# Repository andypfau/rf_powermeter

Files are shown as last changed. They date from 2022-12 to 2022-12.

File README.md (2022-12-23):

RF Powermeter
=============

A 10 MHz to 8 GHz RF power meter with USB connectivity.

## Design



## Photos

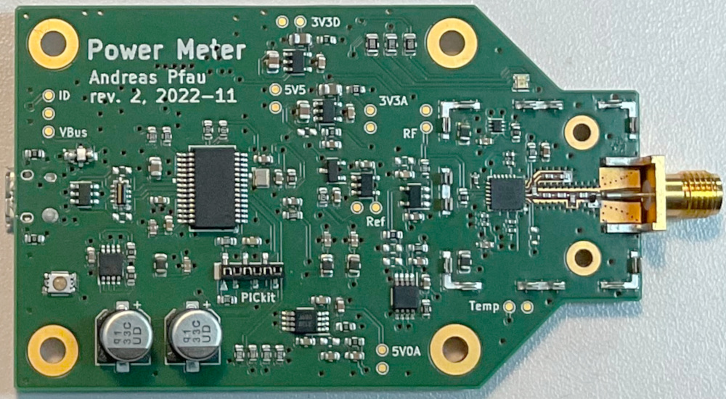
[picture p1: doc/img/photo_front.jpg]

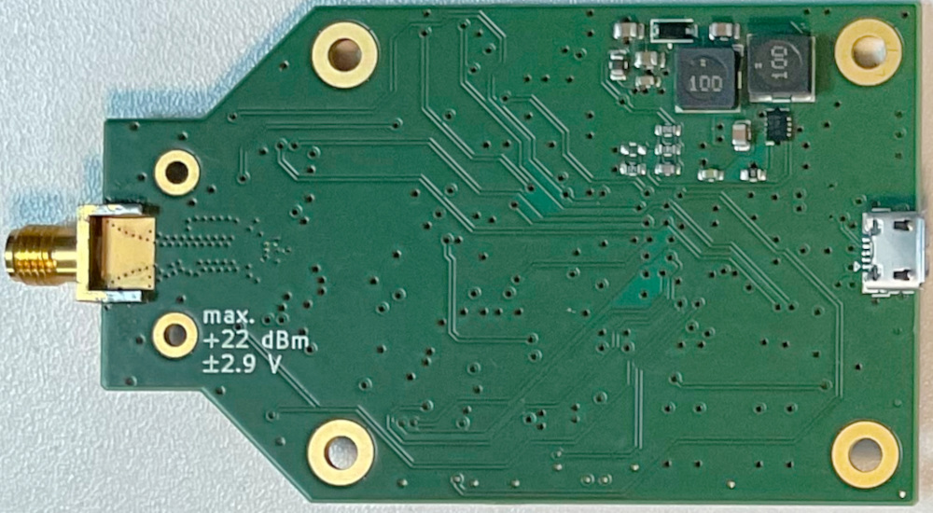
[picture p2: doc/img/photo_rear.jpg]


## Project Status

The hardware is working. The firmware is considered beta, but all functionality is implemented, and should work.

### Thoughts on Design

- The SMA connector is quite cheap, and will probably not last long (no stainless steel). Also, with the current design, the SMA tighening torque might break the solder connectio to the PCB (happened during testing).
- The HMC602 is EOL (see production notes below).

## Further Reading

- [RF Design](./doc/rfdesign.md)
- [Design Tools](./doc/designtools.md)
- [Production](./doc/production.md)
- [Serial Interface](./doc/serial.md)
- [Measurements](./doc/measurements.md)
- [Hardware Revisions](./doc/hwrev.md)

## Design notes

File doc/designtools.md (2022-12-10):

Design Tools
============

- PCB: [KiCad 6](https://www.kicad.org/)
- MCU: [MPLABX 6 IDE](https://www.microchip.com/en-us/tools-resources/develop/mplab-x-ide), [PICkit 4](https://www.microchip.com/en-us/education/developer-help/learn-tools-software/programmers-debuggers/pickit4)

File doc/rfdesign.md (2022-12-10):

RF Design
=========

## PCB Stackup

The PCB was produced with the 4-layer stackup from [Aisler](https://aisler.net/) (as of 2022):

| Layer | Base Th. | Final Th. | Material | εr | Df |
|---|---|---|---|---|---|
| Mask  | | | Elppemer AS 2467 SM-DG | 3.70 | |
| Top | 18 µm | 40 µm | Copper | | |
| | 69 µm | 68.13 µm  | Prepreg 1080 / R-1551 (W) | 4.30 | 0.013 |
| | 69 µm | 68.13 µm  | Prepreg 1080 / R-1551 (W) | 4.30 | 0.013 |
| 2 | 35 µm | 35 µm | Copper | | |
| | 1130 µm  | 1130 µm | FR4 Core / R-1566 (W) | 4.60 | 0.010 |
| 3 | 35 µm | 35 µm | Copper | | |
| | 69 µm | 68.13 µm  | Prepreg 1080 / R-1551 (W) | 4.30 | 0.013 |
| | 69 µm | 68.13 µm  | Prepreg 1080 / R-1551 (W) | 4.30 | 0.013 |
| Bot.  | 18 µm | 40 µm | Copper | | |
| Mask  | | | Elppemer AS 2467 SM-DG | 3.70 | |

The dielectric parameters are in the range from 2..6 GHz; for more details, [see here](https://industrial.panasonic.com/ww/products/pt/halogen-free/models/R-1566%25252FR-1551).

## RF Structures

The RF structures were simulated and optimized in [CST](https://www.3ds.com/products-services/simulia/products/cst-studio-suite/).

### Coplanar Waveguide

S-Parameters of a 20 mm trace:

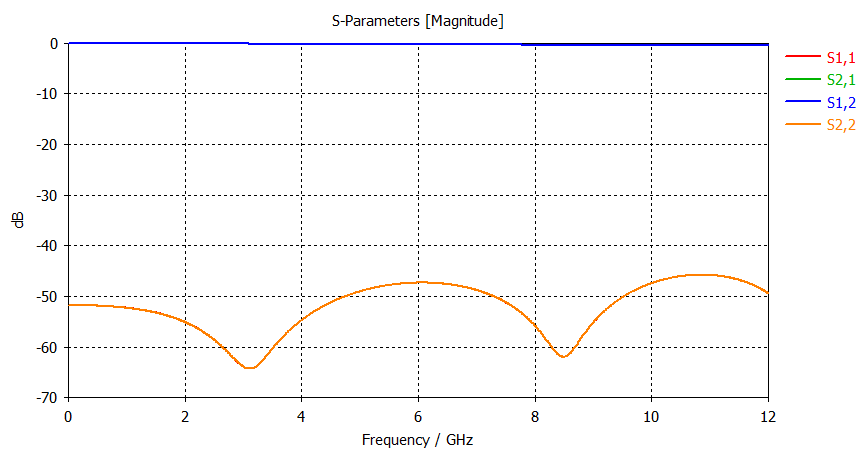
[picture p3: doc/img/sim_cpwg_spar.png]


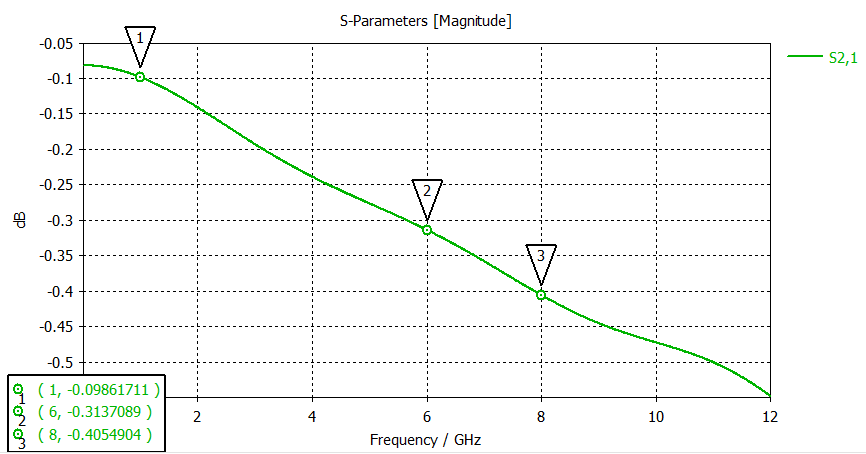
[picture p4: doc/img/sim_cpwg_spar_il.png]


| Frequency | Loss |
|---|---|
| 1 GHz | 0.049 dB/cm |
| 6 GHz | 0.16 dB/cm  |
| 8 GHz | 0.20 dB/cm  |

Geometry:

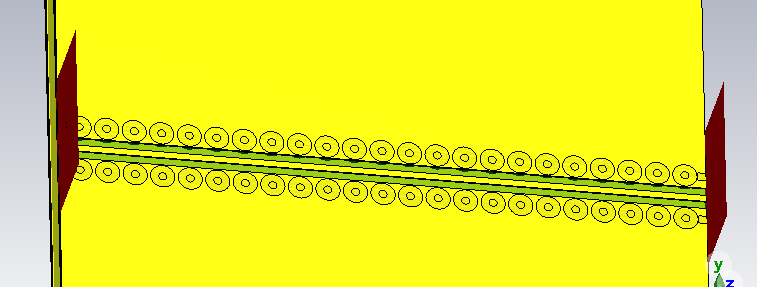
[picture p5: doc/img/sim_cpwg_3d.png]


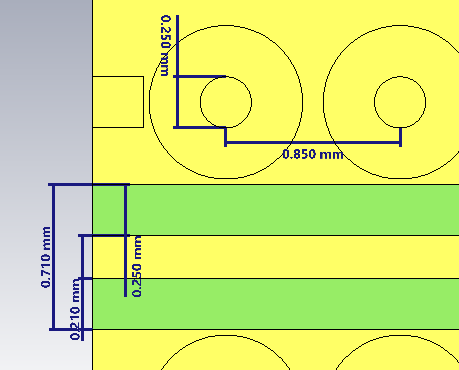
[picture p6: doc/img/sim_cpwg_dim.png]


#### Sensitivity

Swept Parameters:

- Tline width: ±0.3 mm
- Prepreg thickness: ±20 µm
- Prepreg Dk: ±0.1 → almost no impact

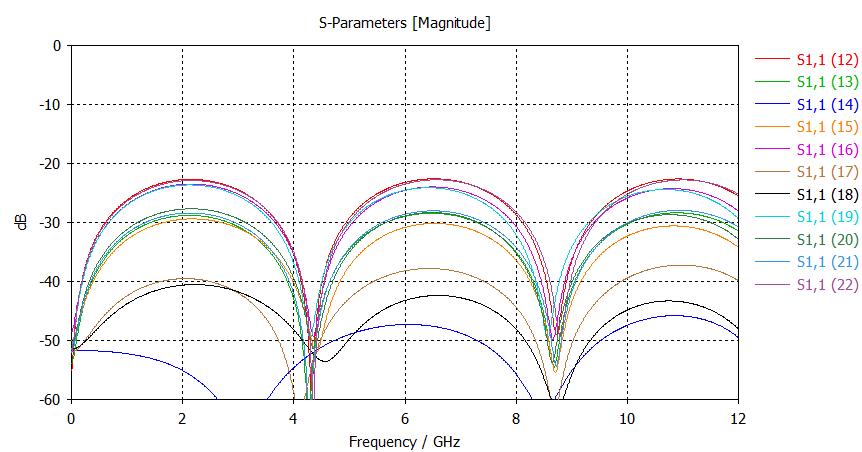
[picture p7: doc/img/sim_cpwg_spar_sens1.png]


Swept Parameters:

- Via diameter: 0.25 mm, 0.50 mm
- Via annular ring: 0.25 mm, 0.50mm
- Gap between annular rings is fixed at 0.025 mm.

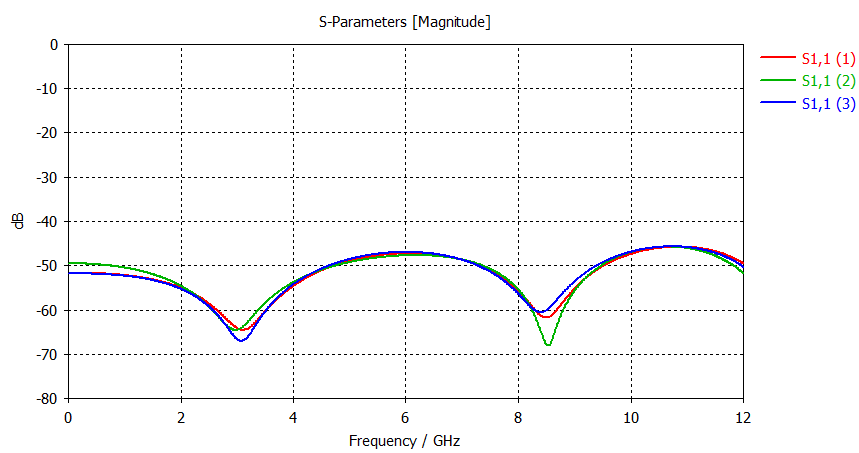
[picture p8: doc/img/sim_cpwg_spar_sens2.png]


### SMA Transition

S-Parameters:

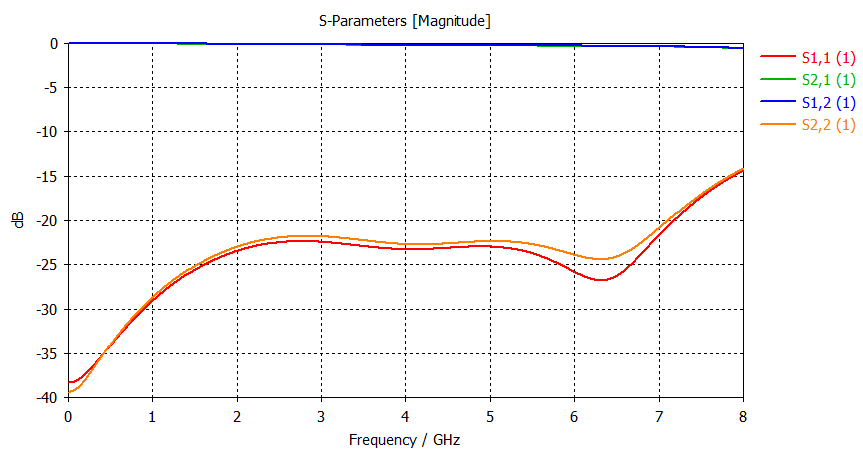
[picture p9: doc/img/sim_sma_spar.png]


Geometry:

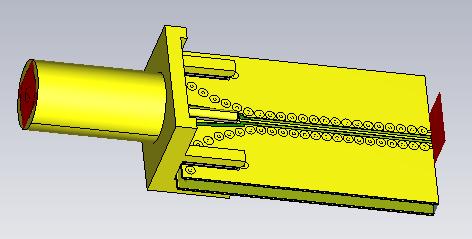
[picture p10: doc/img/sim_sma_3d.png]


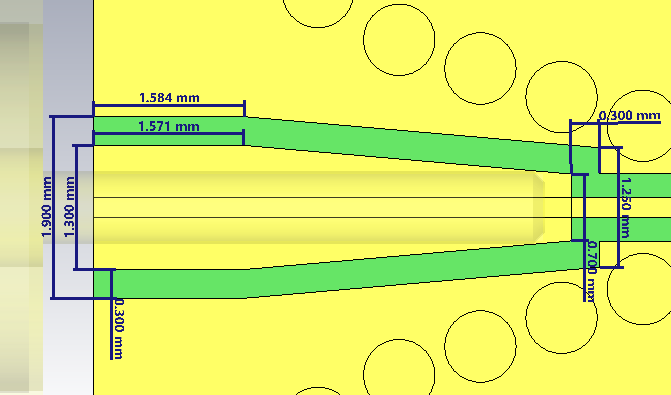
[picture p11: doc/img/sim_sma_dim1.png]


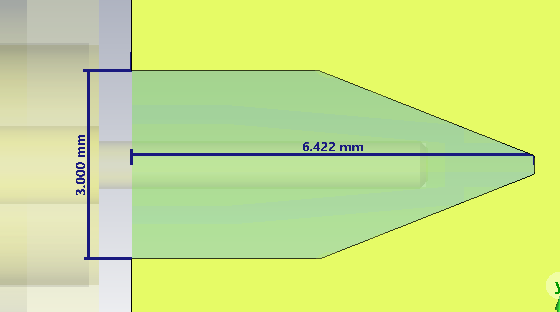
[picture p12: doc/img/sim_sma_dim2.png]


### 0402 Resistors

S-Parameters:

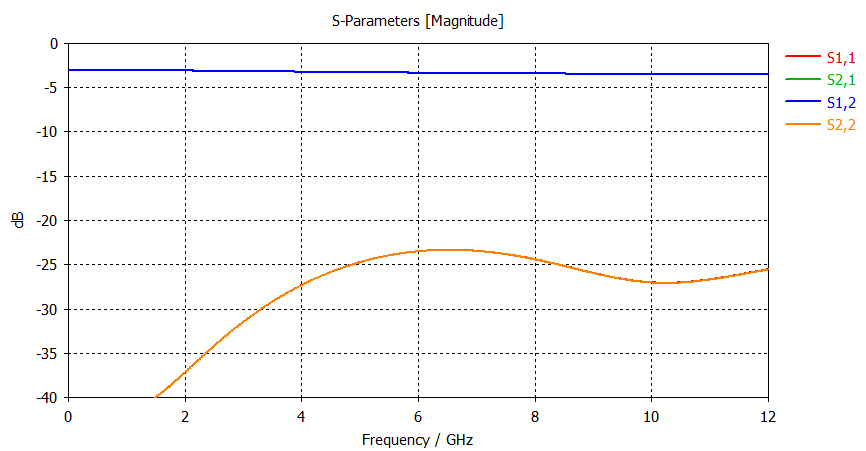
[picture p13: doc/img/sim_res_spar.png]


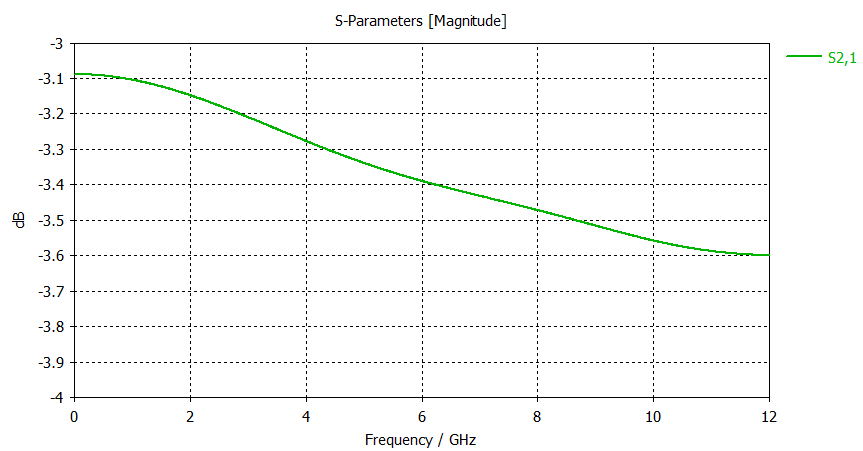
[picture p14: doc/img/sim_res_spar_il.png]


Impact of GND-Cutout:

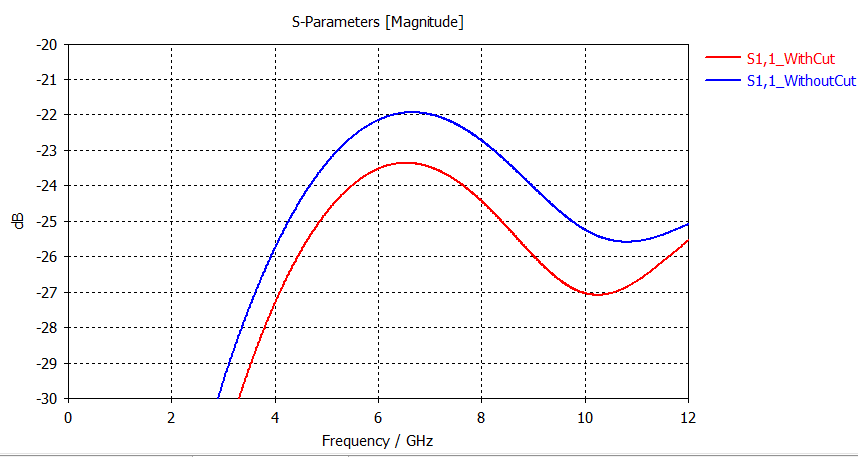
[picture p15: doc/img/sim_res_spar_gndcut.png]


Geometry:

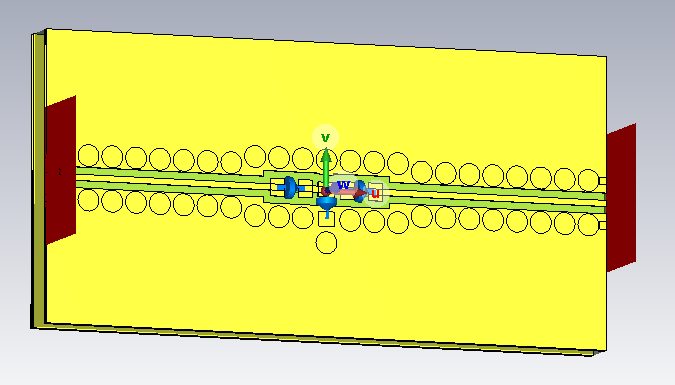
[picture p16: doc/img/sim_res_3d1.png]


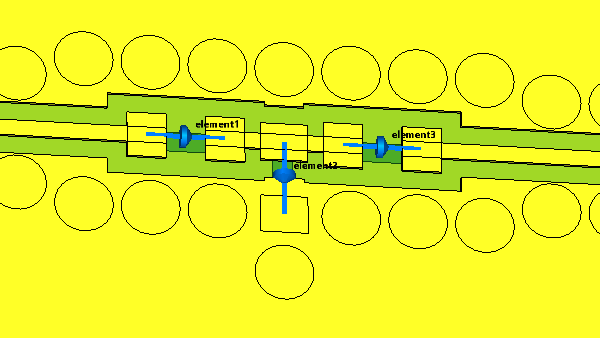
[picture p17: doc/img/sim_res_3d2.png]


Top Cu:

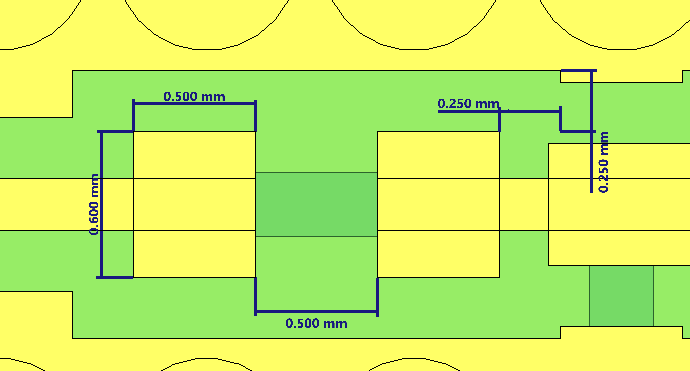
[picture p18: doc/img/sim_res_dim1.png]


Inner (GND) Cu:

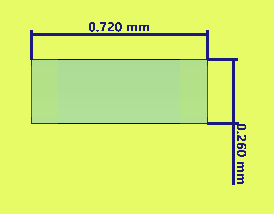
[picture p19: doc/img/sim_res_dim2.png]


## QFN Transition

S-Parameters:

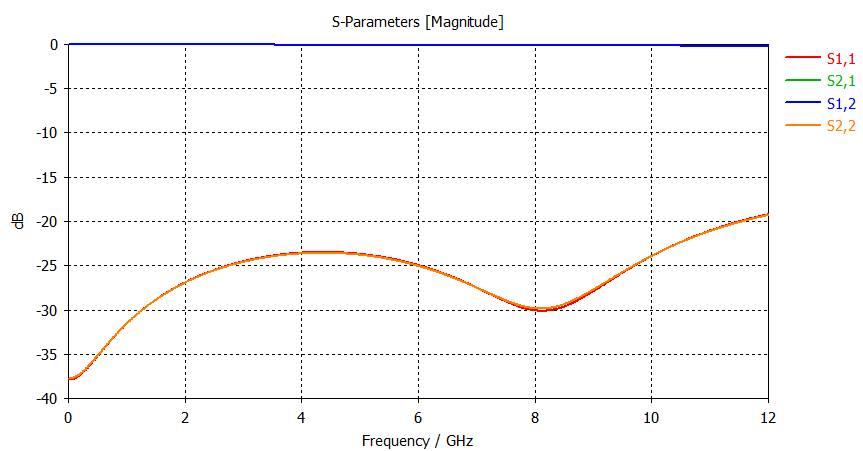
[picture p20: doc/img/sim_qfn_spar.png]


Geometry:

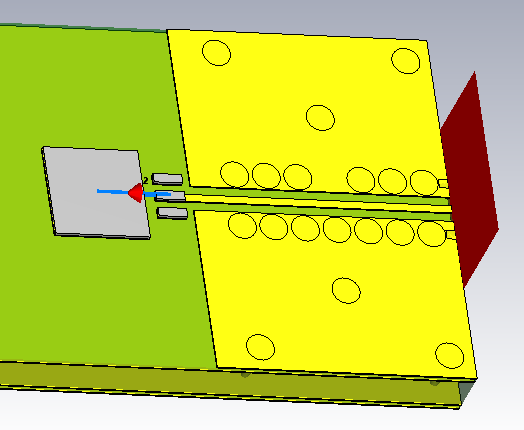
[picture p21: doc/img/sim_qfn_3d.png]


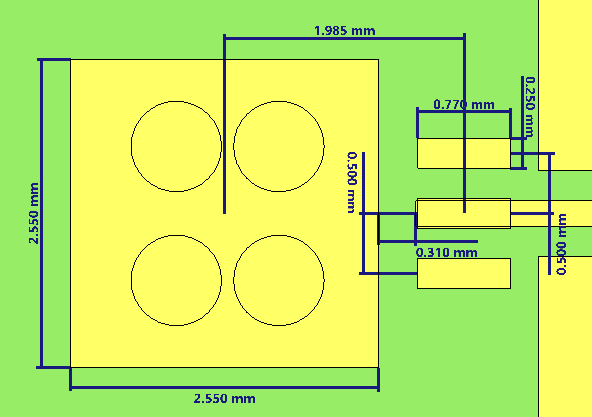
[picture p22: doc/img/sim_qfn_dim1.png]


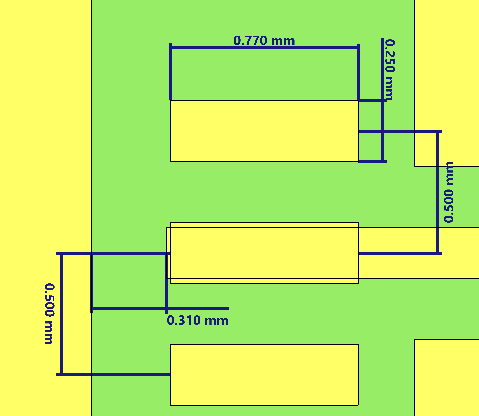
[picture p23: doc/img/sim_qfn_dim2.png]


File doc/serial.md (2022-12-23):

Serial Interface
================

# Getting Started

1. Connect the Powermeter via USB to your PC
	- both under Windows and under Linux, a virtual serial port should be detected without drivers needed
2. Connect to the virtual serial port e.g. with *PuTTY*, or e.g. with the `screen` command

# UI Mode

Press the `Esc` key to enter UI mode.

	-35.103 dB
	
	          v
	| ' | ' | ' | ' | ' | ' | ' |
	
	Cnt  Avg 16  3000 MHz

Valid commands:

- `a`: enter number of averages (must be a power of 2, in the range 1..512)
- `c`: continuous trigger mode
- `d`: display diagnostic data
- `t`: trigger a single measurement
- `f`: enter frequency in MHz (for compensation data; must be in the range 10..8000)
- `h`: display help
- `l`: turn compensation on/off
- `Esc`: re-draw the screen

# Remote Mode

Send a `\0` character (i.e. ASCII code zero) to enter remote mode. All commands and responses are terminated by `\n` (i.e. ASCII code 10) Valid commands:

- `a<int>\n`: set number of averages
	- Must be a power of two
	- E.g. `a32\n` to set 32 averages
- `d\n`: diagnostics
	- Returns three semicolon-separated list of three values: the measured voltage of 5V0USB (USB bus voltage) in volts, the measured voltage of 5V0A (analog supply) in volts, and the tmeperature sensor reading on °C
	- E.g. `d\n` → `4.999;5.010;32.105\n`
- `e\n`: get last error
	- Returns an error code that is zero in the case of no error.
	- E.g. `e\n` → `0\n`
- `f<int>\n`: set frequency, in MHz
	- Must be in the range 10..8000
	- E.g. `f1100\n` to set to 1.1 GHz
- `l<int>\n`: enable/disable compensation
	- Must be 1 (enable) or 0 (disable)
	- E.g. `l1\n` to enable compensation
- `m<r|w><hex><hex>\n`: access EEPROM
	- Read from memory: send `r`, followed by exactly four hexadecimal digits (address); the response will be exactly four hexadecimal digits (data)
	- Write to memory: send `w`, followed by exactly four hexadecimal digits (address), followed by exactly four hexadecimal digits (data)
	- E.g. `mw00010002\n` to write 0x0002 to address 0x0001
	- E.g. `mr0001\n` to read from address 0x0001 → e.g. `0002\n`
- `t\n`: trigger a measurement
	- Ehe response will be sent as a signed floating-point string, followed by `\n`
	- E.g. `t\n` → `-30.205\n`
- `\0`: enter remote mode

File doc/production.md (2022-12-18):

Production
==========

## Tools and Material

- PCB and stencil: [Aisler 4-layer](https://aisler.net/)
- Stencil registration tool: [Eurocrictuis ec manual tool](https://www.eurocircuits.de/ec-registration-system-details-platine-schablone/)
- Tools for pick&place: VAC-12000 vacuum pickup, [SWIFT S41-20 Binocular Stereo Microscope](https://us.swiftmicroscopes.com/collections/stereo-microscope/products/swift-s41-20-binocular-stereo-microscope-with-10x-20x-and-1w-led-illumination)
- Solder paste: [Chipquik NC191SNL50T5](https://www.chipquik.com/store/product_info.php?products_id=473023) (Sn96.5/Ag3.0/Cu0.5, 217..220 °C melting point, no-clean flux, T5 / 15-25 microns)
- Vapor phase liquid: [Galden HS240](https://www.solvay.com/en/brands/galden-pfpe) (240 °C boiling point)

## Notes on Components

The key component, the [HMC602LP4E](https://www.analog.com/en/products/hmc602.html) RF power sensor, was [discontinued](https://www.analog.com/media/en/PCN/ADI_PDN_22_0023_Rev_B_Form.pdf) shortly after I started the project.

There is no pin-compatible replacement, but ADI recommends the [AD8318](https://www.analog.com/en/products/ad8318.html) as a replacement. At a first glance, it looks like it could be used with only small PCB modifications. However, it has a different pitch (0.65 mm vs. 0.5 mm), so the pad geometry may have to be adjusted.

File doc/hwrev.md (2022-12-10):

Hardware Revisions
==================

##  Rev. 1
- Problems:
	- USB D+ and D- lines are crossed → use flipped USB connector instead.
	- RF component footprints have solder resist on the pads → revise solder mask.
	- HMC602 footprint does not fit (pads are wider than package).

## Rev. 2
- Problems:
	- Pin numbering of button symbol is wrong (causes PGC to be shorted).
	- RF Temp requires a voltage divider towards MCU
	- Moved USB connector to PCB rear side (to swap D+ and D-).
- Changes:
	- Fixed solder resist on RF component footprints
	- Revised HMC602 footprint (pads were wider than package).
	- Fixed TMP112 footprint (pads were too wide).
	- Added more drill-holes close to RF connector.

## Rev. 3
Not produced yet.

- Changes:
	- Fixed button symbol and layout.
	- Added voltage divider between RF Temp output and MCU ADC input.
- Ideas:
	- Add "GND-island" around DCDC.
	- Add a GND clamp for easier hardware-debugging.

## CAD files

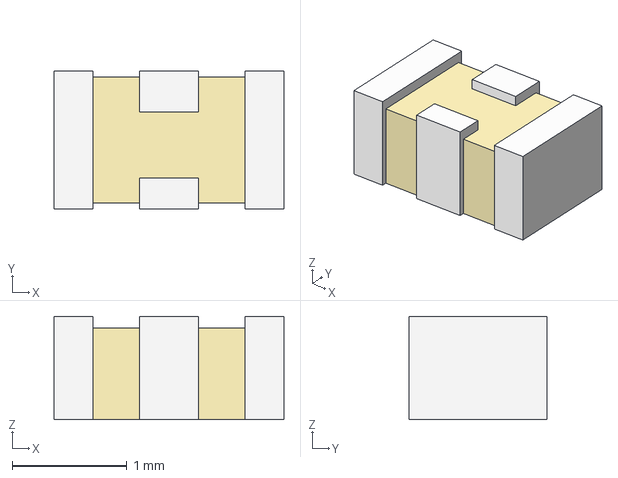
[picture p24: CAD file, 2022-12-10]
hardware/KiCad/3d/Capacitor_Feedthru_0805.step
2.00 x 1.20 x 0.9 mm

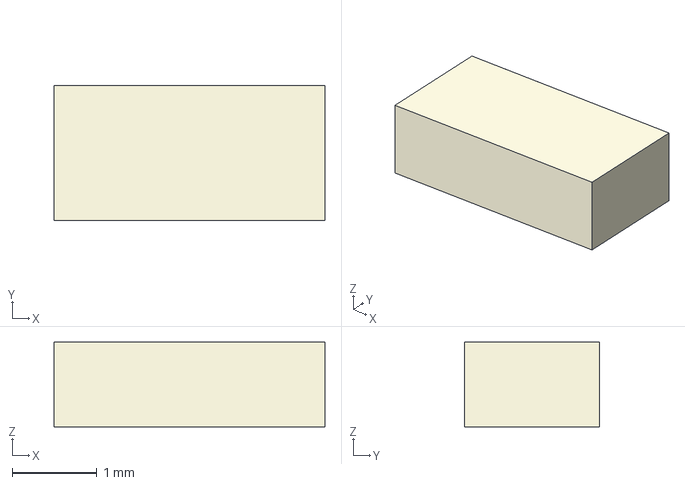
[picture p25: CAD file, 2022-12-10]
hardware/KiCad/3d/EZA-DLU.stp
3.20 x 1.60 x 1.00 mm

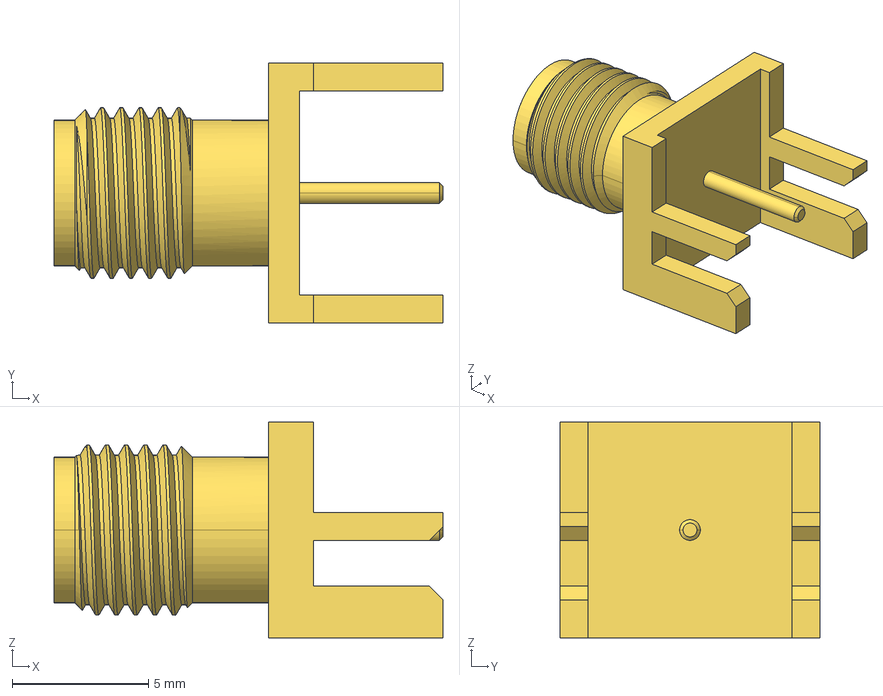
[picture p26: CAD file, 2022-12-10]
hardware/KiCad/3d/Molex_SMA_732511150.stp
14.3 x 9.53 x 7.92 mm

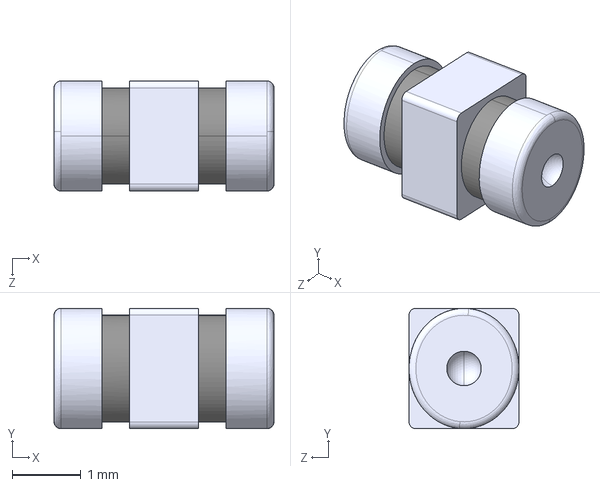
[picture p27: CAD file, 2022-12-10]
hardware/KiCad/3d/NFE31PT471F1E9L.step
3.20 x 1.75 x 1.60 mm

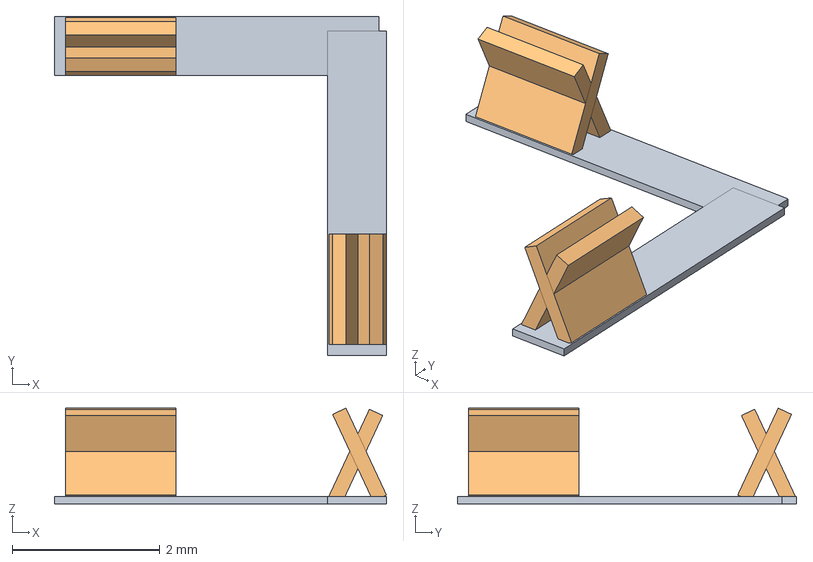
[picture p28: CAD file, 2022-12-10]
hardware/KiCad/3d/S0981-46R.stp
4.50 x 4.60 x 1.30 mm

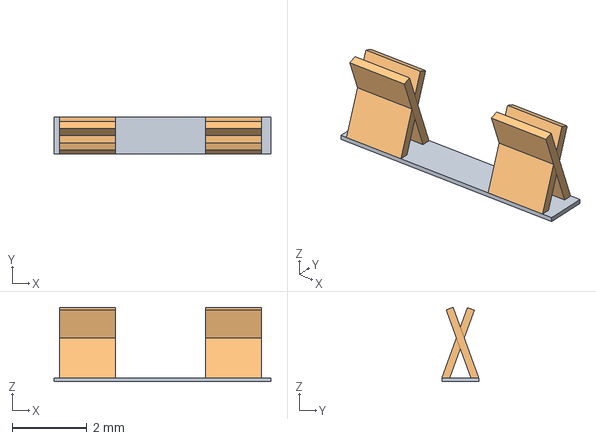
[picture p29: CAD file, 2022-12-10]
hardware/KiCad/3d/S0971-46R.stp
5.80 x 1.00 x 1.99 mm

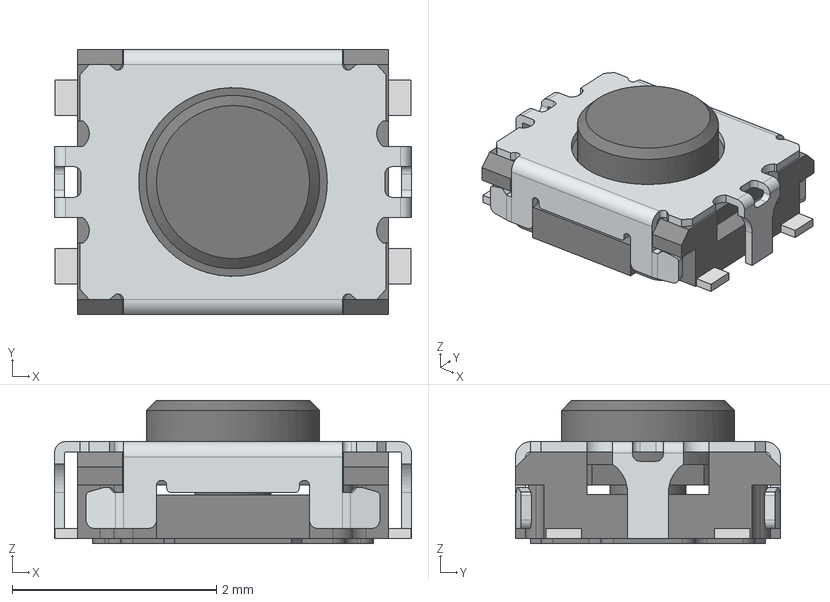
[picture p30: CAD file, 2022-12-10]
hardware/KiCad/3d/STP_4351x10148xx (rev1).stp
3.50 x 2.60 x 1.40 mm
Base
Stem
Frame
Pin x 4

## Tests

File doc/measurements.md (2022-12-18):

Measurements
============

## Summary

- Return Loss: -12 dB up to 6 GHz, which is good enough for a hobby project.
- Measurement error: no dips/resonances/etc, can easily be compensated with LUT.
- Linearity: around 1 dB error over a 20 dB range, which is more than expected, but acceptable for a hobby project.
- Generated noise: no significant noise detected.

The DUT reported a temperature of 38 °C during the measurement.

## RF Measurements

### Return Loss

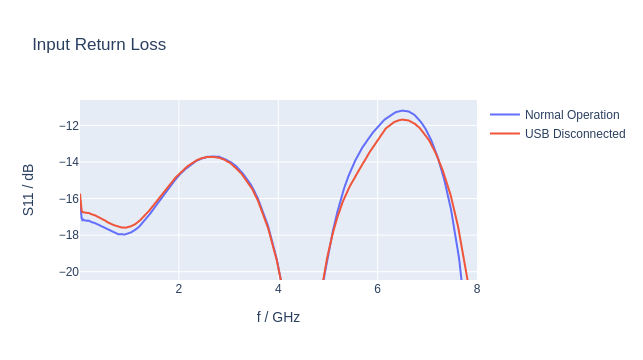
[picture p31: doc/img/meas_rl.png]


Setup: powermeter → network analyzer.

### Measurement Error

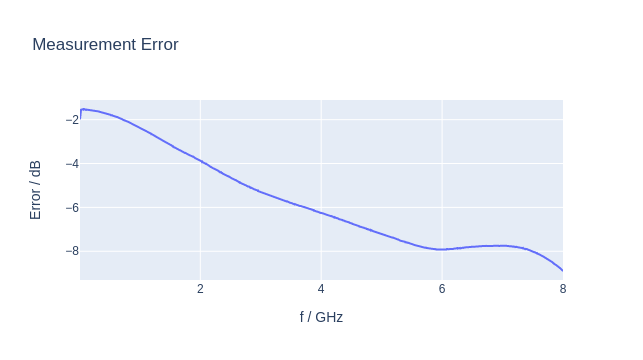
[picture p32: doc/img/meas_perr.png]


Setup: signal source → power divider → powermeter (bench instrument) | powermeter (DUT).

There is a small systematic error, because there were different adapters on each leg of the divider.

#### Linearity

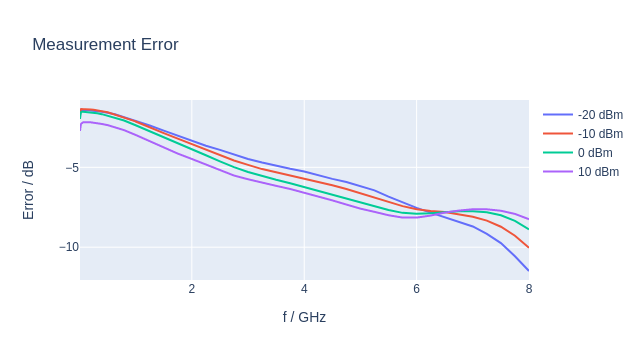
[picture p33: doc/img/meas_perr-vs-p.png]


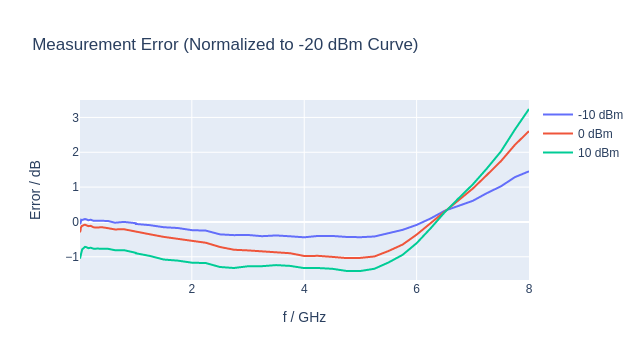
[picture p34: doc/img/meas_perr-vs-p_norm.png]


### Generated Noise

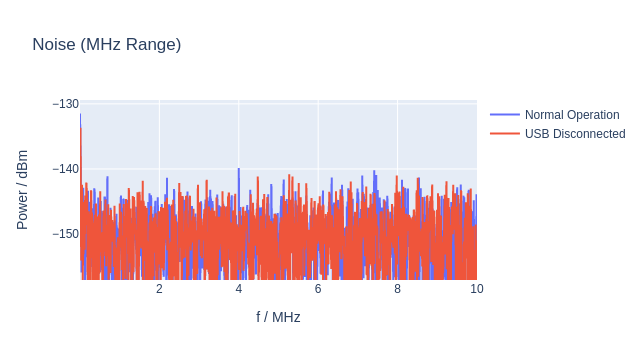
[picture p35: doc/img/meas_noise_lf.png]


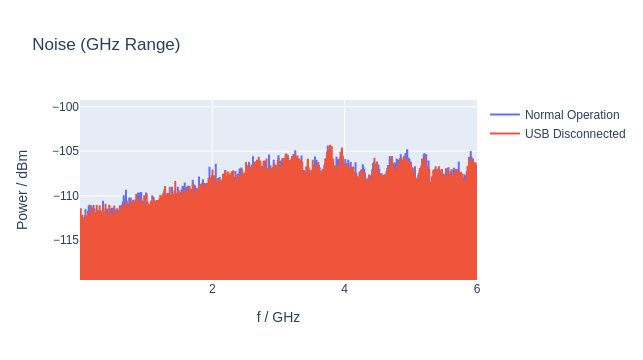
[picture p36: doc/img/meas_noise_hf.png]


Setup: powermeter → spectrum analyzer.

For the different frequency ranges, the measured noisefloor levels differ; this is because the RBW was changed, in order to speed up the measurement time. However, the measurements show that there is no change in noisefloor when turning the DUT on or off.

## DC Rail measurements

### Levels

- 5V0USB: 4.79 V
- 5V5: 5.64 V
- 5V0A: 4.99 V
- 3V3A: 3.29 V
- 3V3D: 3.29 V
- Ref: 2.998 V
- RF: 2.05 V (with RF input disconnected/open)

Measured with DMM.

### Switching Noise

- DC-DC output: around 30 mVpp, 2 MHz and harmonics
- LDOs output: around 25 mVpp, 2 MHz, harmonics below noise

Measured with Oscilloscope and 1 MΩ probe.

## Bench Instruments

- Network analyzer: Rohde & Schwarz ZVA40, 4 ports (calibrated with e-cal)
- Signal source: Keysight E8257D
- Power meter: Keysight N1914A (calibrated with internal zero+cal)
- Spectrum analyzer: Keysight N9041B
- Power divider: Keysight 11636C
- DMM: Fluke 175 (*out of cal*)
- Oscilloscope: Siglent SDS1204X-E (*out of cal*)

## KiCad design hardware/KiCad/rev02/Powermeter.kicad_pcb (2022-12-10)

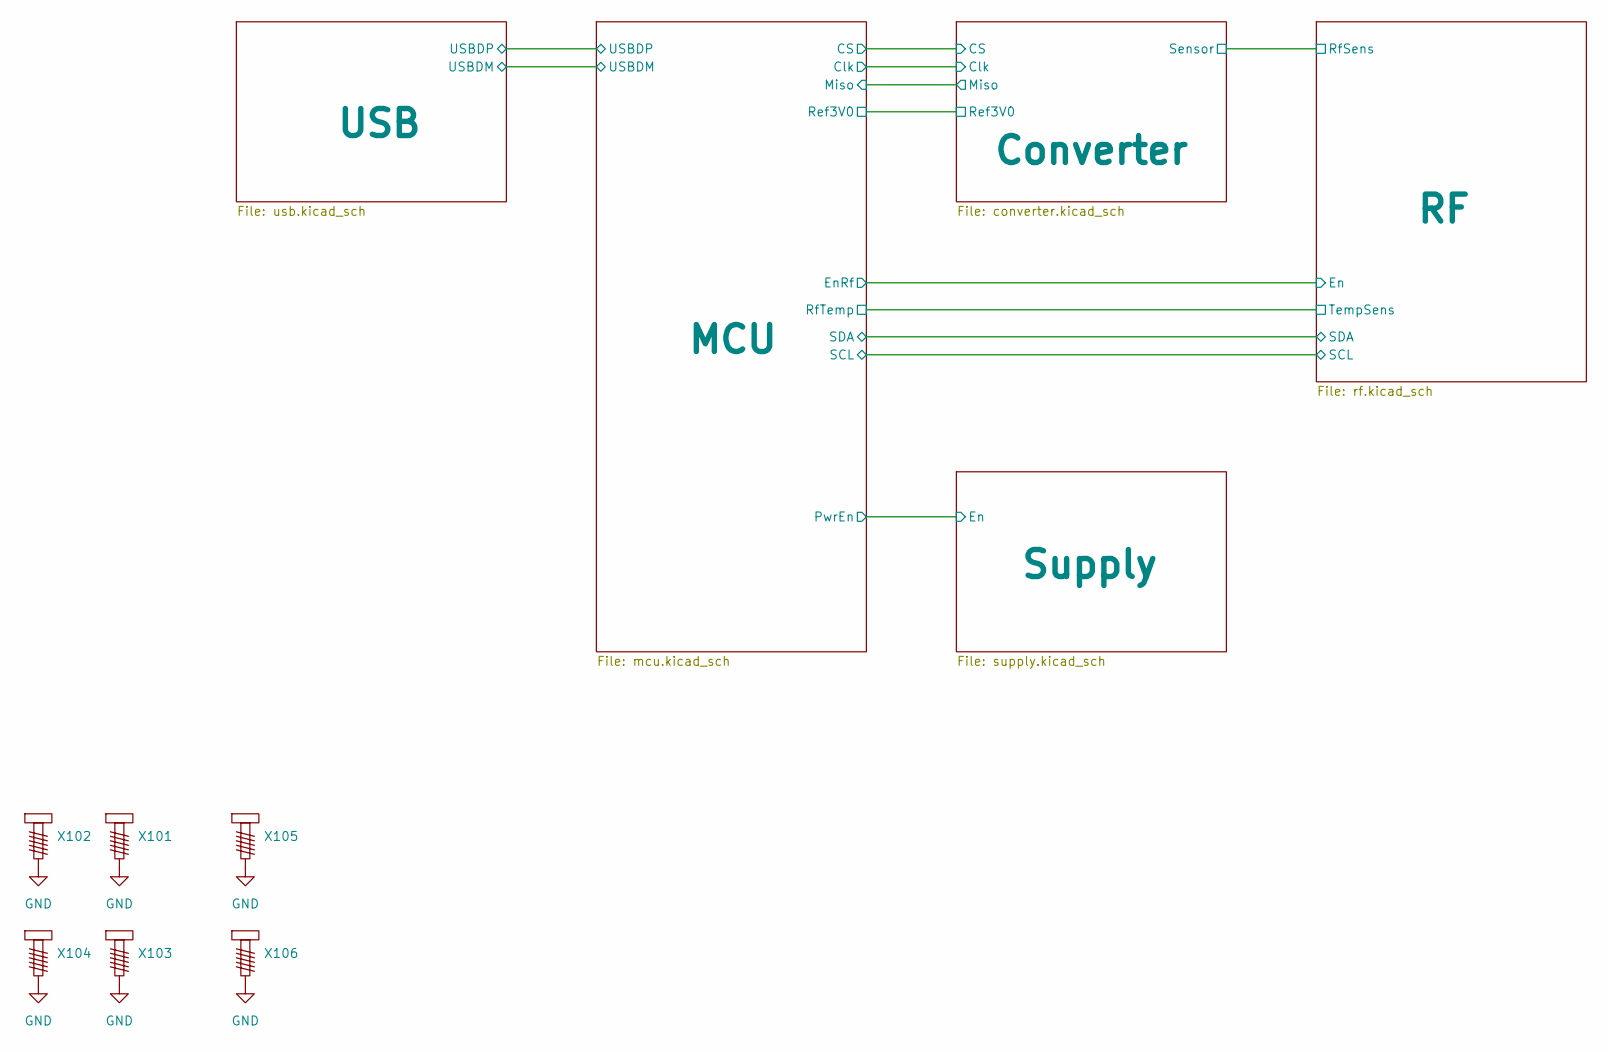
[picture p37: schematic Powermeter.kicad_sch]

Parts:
X101, X102, X103, X104: MountingHoleConnected; MountingHole_3.2mm_M3_Pad
X105, X106: MountingHoleConnected; MountingHole_2.2mm_M2_Pad

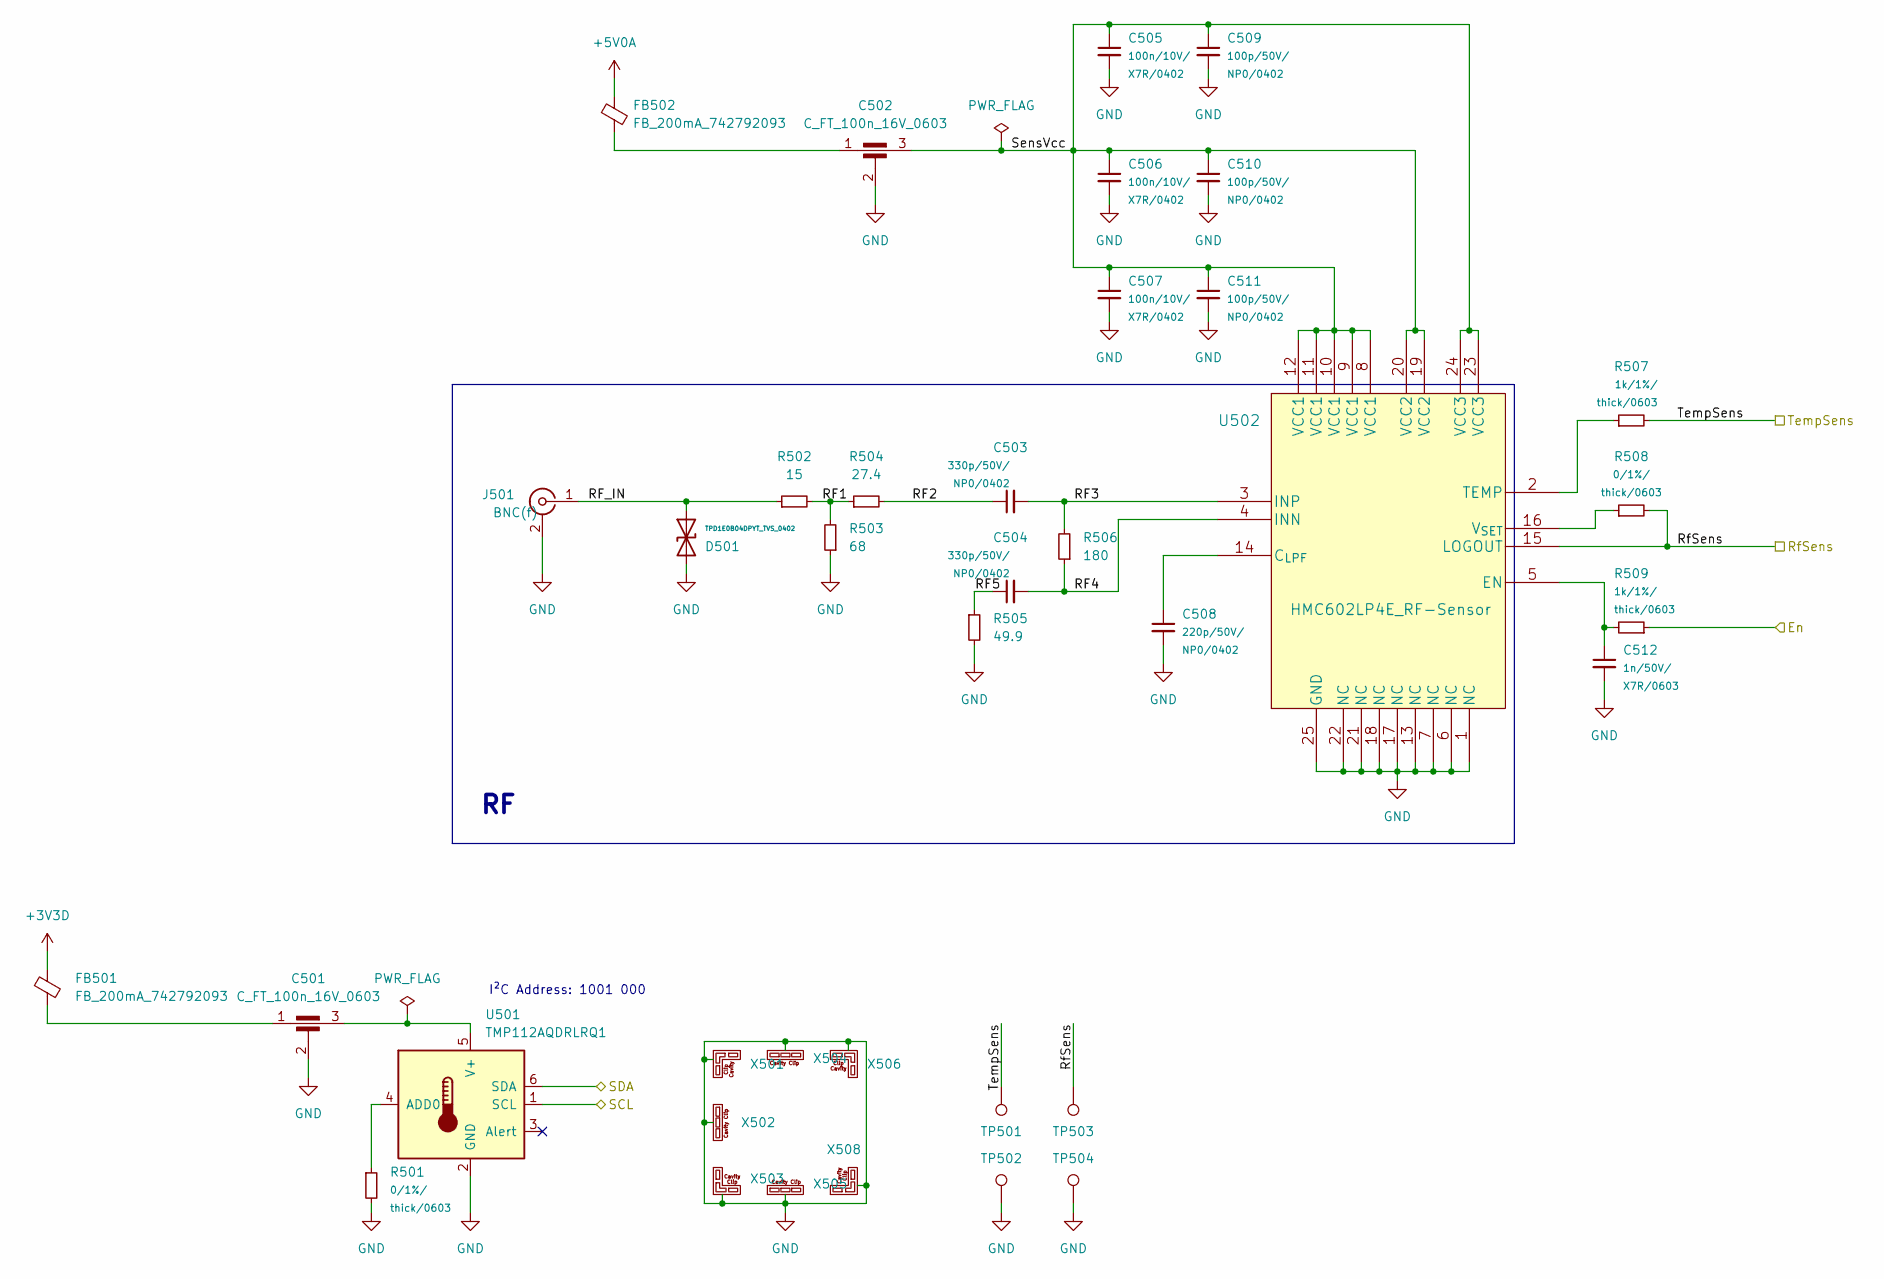
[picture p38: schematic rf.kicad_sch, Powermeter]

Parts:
C501, C502: C_FT_100n_16V_0603; C_Feedthru_0603
C503, C504: C_330p_50V_NP0_0402_small; R_0402_RF_Thru
C505, C506, C507: C_100n_10V_X7R_0402_small; C_0402_1005Metric
C508: C_220p_50V_NP0_0402_small; R_0402_RF_ToGND
C509, C510, C511: C_100p_50V_NP0_0402_small; C_0402_1005Metric
C512: C_1n_50V_X7R_0603_small; C_0603_1608Metric
D501: TPD1E0B04DPYT_TVS_0402; R_0402_RF_ToGND
FB501, FB502: FB_200mA_742792093; C_0805_2012Metric
J501: SMA-f_Molex732511150; Molex_SMA_732511150_Handsolder
R501, R508: R_0_1P_thick_0603_small; R_0603_1608Metric
R502: 15; R_0402_RF_Thru
R503: 68; R_0402_RF_ToGND
R504: 27.4; R_0402_RF_Thru
R505: 49.9; R_0402_RF_ToGND
R506: 180; R_0402_RF_Thru
R507, R509: R_1k_1P_thick_0603_small; R_0603_1608Metric
TP501, TP502, TP503, TP504: TestPoint; TestPoint_Pad_D1.0mm
U501: TMP112AQDRLRQ1; SOT-563_Smallpads
U502: HMC602LP4E_RF-Sensor; HMC602LP4
X501, X503, X506, X508: CavityClip_Angled_S0981-46R; S0981-46R
X502, X504, X505: CavityClip_Straight_S0971-46R; S0971-46R

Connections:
+3V3D: FB501.1; also elsewhere on the board
+5V0A: FB502.1; also elsewhere on the board
/MCU/EnRf: R509.1; also elsewhere on the board
/MCU/SCL: U501.1 (SCL); also elsewhere on the board
/MCU/SDA: U501.6 (SDA); also elsewhere on the board
/RF/RF1: R502.2, R503.2, R504.1
/RF/RF2: C503.1, R504.2
/RF/RF3: C503.2, R506.2, U502.3 (INP)
/RF/RF4: C504.2, R506.1, U502.4 (INN)
/RF/RF5: C504.1, R505.1
/RF/RF_IN: D501.1 (A1), J501.1 (In), R502.1
/RF/RfSens: R508.2, TP503.1, U502.15 (LOGOUT); also elsewhere on the board
/RF/SensVcc: C502.3, C505.1, C506.1, C507.1, C509.1, C510.1, C511.1, U502.8 (VCC1), U502.9 (VCC1), U502.10 (VCC1), U502.11 (VCC1), U502.12 (VCC1), U502.19 (VCC2), U502.20 (VCC2), U502.23 (VCC3), U502.24 (VCC3)
/RF/TempSens: R507.2, TP501.1; also elsewhere on the board
unnamed: C501.1, FB501.2
unnamed: C501.3, U501.5 (V+)
unnamed: C502.1, FB502.2
unnamed: C508.1, U502.14 (C_{LPF})
unnamed: C512.1, R509.2, U502.5 (EN)
unnamed: R501.1, U501.4 (ADD0)
unnamed: R507.1, U502.2 (TEMP)
unnamed: R508.1, U502.16 (V_{SET})

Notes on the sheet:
I²C Address: 1001 000

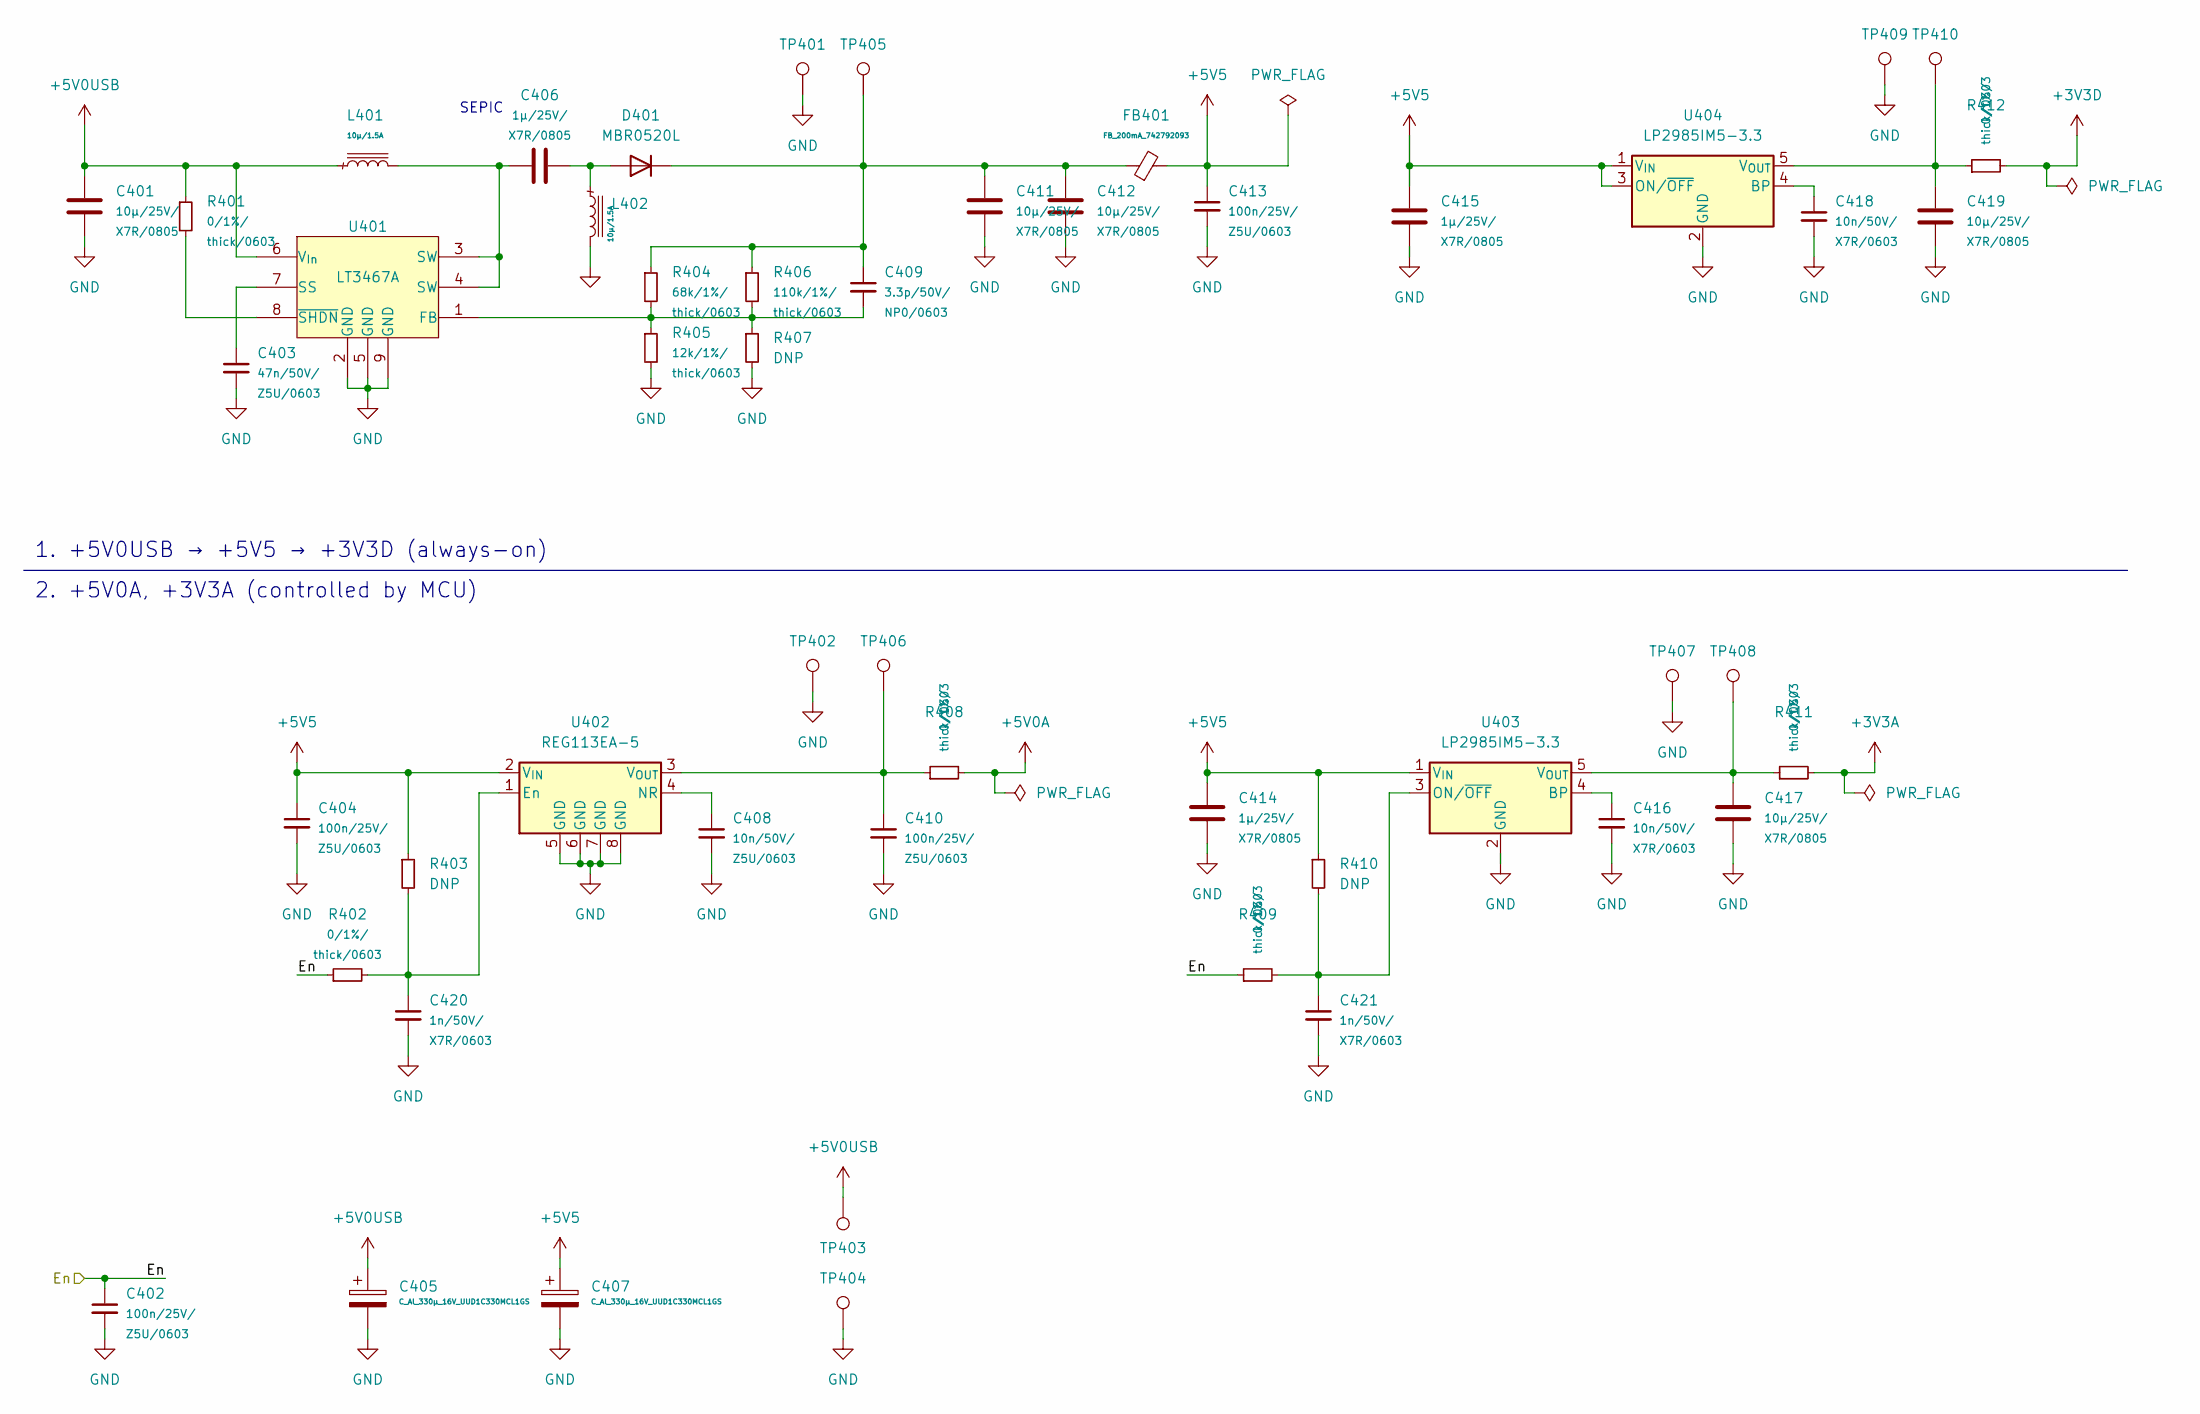
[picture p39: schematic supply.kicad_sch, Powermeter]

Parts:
C401, C411, C412, C417, C419: C_10µ_25V_X7R_0805; C_0805_2012Metric
C402, C404, C410, C413: C_100n_25V_Z5U_0603_small; C_0603_1608Metric
C403: C_47n_50V_Z5U_0603_small; C_0603_1608Metric
C405, C407: C_Al_330µ_16V_UUD1C330MCL1GS; CP_Elec_6.3x5.8
C406, C414, C415: C_1µ_25V_X7R_0805; C_0805_2012Metric
C408: C_10n_50V_Z5U_0603_small; C_0603_1608Metric
C409: C_3p3_50V_NP0_0603_small; C_0603_1608Metric
C416, C418: C_10n_50V_X7R_0603_small; C_0603_1608Metric
C420, C421: C_1n_50V_X7R_0603_small; C_0603_1608Metric
D401: MBR0520L; D_SOD-123
FB401: FB_200mA_742792093; C_0805_2012Metric
L401, L402: WE744053100_PowerInd; L_Wuerth_WE-TPC-6.3mm
R401, R402, R408, R409, R411, R412: R_0_1P_thick_0603_small; R_0603_1608Metric
R403, R410: DNP; C_0603_1608Metric
R404: R_68k_1P_thick_0603_small; R_0603_1608Metric
R405: R_12k_1P_thick_0603_small; R_0603_1608Metric
R406: R_110k_1P_thick_0603_small; R_0603_1608Metric
R407: DNP; R_0603_1608Metric
TP401, TP402, TP403, TP404, TP405, TP406, TP407, TP408, TP409, TP410: TestPoint; TestPoint_Pad_D1.0mm
U401: LT3467A; DFN-8-1EP_2x3mm_P0.5mm_EP0.61x2.2mm
U402: REG113EA-5; VSSOP-8_3.0x3.0mm_P0.65mm
U403, U404: LP2985IM5-3.3; SOT-23-5

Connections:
+3V3A: R411.2; also elsewhere on the board
+3V3D: R412.2; also elsewhere on the board
+5V0A: R408.2; also elsewhere on the board
+5V0USB: C401.1, C405.1, L401.1, R401.1, TP403.1, U401.6 (V_{In}); also elsewhere on the board
+5V5: C404.1, C407.1, C413.1, C414.1, C415.1, FB401.2, R403.1, R410.1, U402.2 (V_{IN}), U403.1 (V_{IN}), U404.1 (V_{IN}), U404.3 (ON/~OFF)
/Supply/En: C402.1, R402.1, R409.1; also elsewhere on the board
unnamed: C403.1, U401.7 (SS)
unnamed: C406.1, L401.2, U401.3 (SW), U401.4 (SW)
unnamed: C406.2, D401.2 (A), L402.1
unnamed: C408.1, U402.4 (NR)
unnamed: C409.1, C411.1, C412.1, D401.1 (K), FB401.1, R404.1, R406.1, TP405.1
unnamed: C409.2, R404.2, R405.1, R406.2, R407.1, U401.1 (FB)
unnamed: C410.1, R408.1, TP406.1, U402.3 (V_{OUT})
unnamed: C416.1, U403.4 (BP)
unnamed: C417.1, R411.1, TP408.1, U403.5 (V_{OUT})
unnamed: C418.1, U404.4 (BP)
unnamed: C419.1, R412.1, TP410.1, U404.5 (V_{OUT})
unnamed: C420.1, R402.2, R403.2, U402.1 (En)
unnamed: C421.1, R409.2, R410.2, U403.3 (ON/~OFF)
unnamed: R401.2, U401.8 (~SHDN)

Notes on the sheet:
1. +5V0USB → +5V5 → +3V3D (always-on)
2. +5V0A, +3V3A (controlled by MCU)
SEPIC

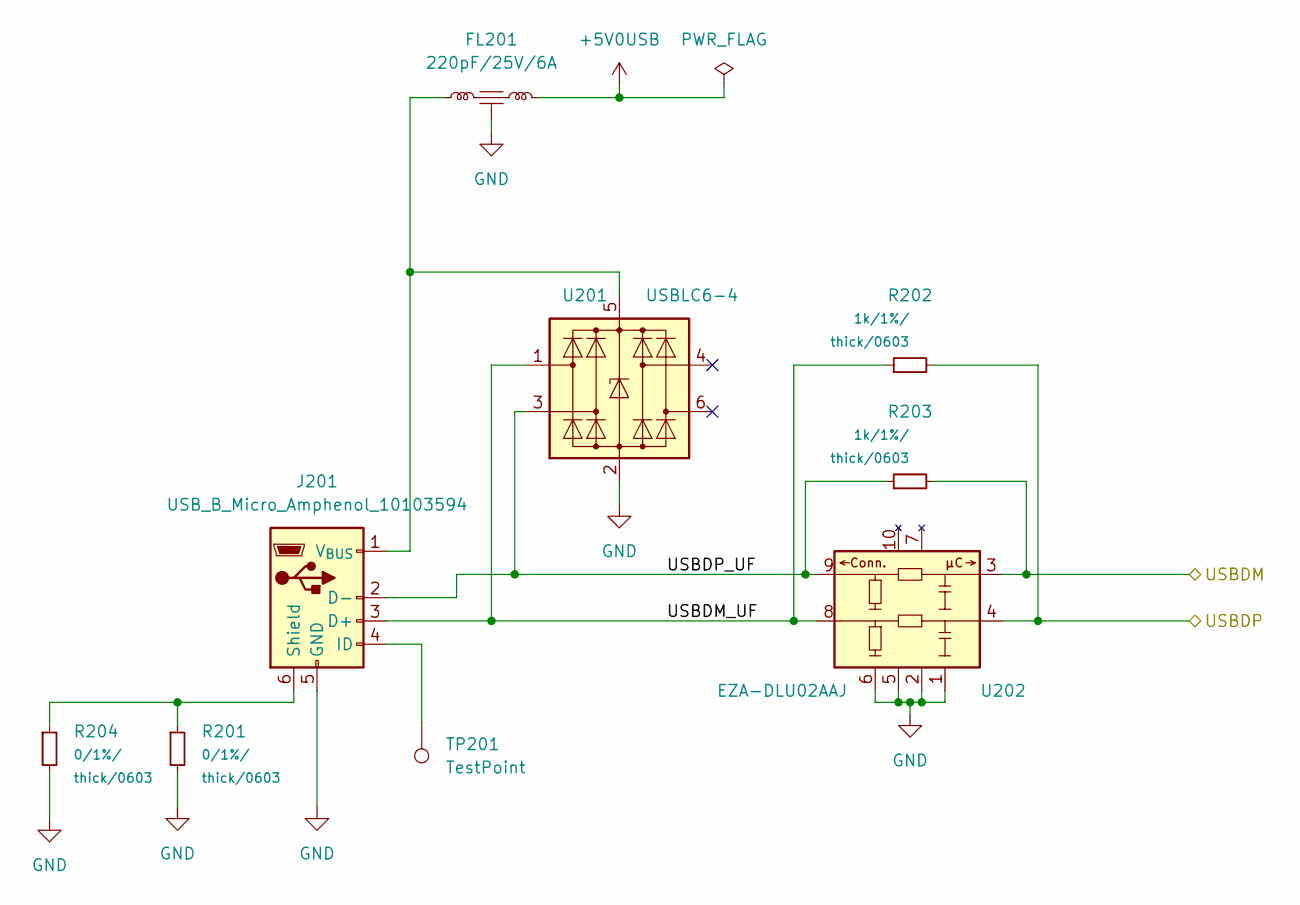
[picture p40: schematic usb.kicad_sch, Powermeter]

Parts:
FL201: NFE31PT221D1E9L_Filter; NFE31PT221D1E9L
J201: USB_B_Micro_Amphenol_10103594; USB_Micro-B_Amphenol_10103594-0001LF_Horizontal
R201, R204: R_0_1P_thick_0603_small; R_0603_1608Metric
R202, R203: DNP; R_0603_1608Metric
TP201: TestPoint; TestPoint_Pad_D1.0mm
U201: USBLC6-4; SOT-23-6
U202: EZA-DLU02AAJ; EZA-DLU

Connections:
+5V0USB: FL201.3; also elsewhere on the board
/MCU/USBDM: R203.2, U202.3 (I/O1); also elsewhere on the board
/MCU/USBDP: R202.2, U202.4 (I/O2); also elsewhere on the board
/USB/USBDM_UF: J201.3 (D+), R202.1, U201.1 (I/O1), U202.8 (I/O4)
/USB/USBDP_UF: J201.2 (D-), R203.1, U201.3 (I/O2), U202.9 (I/O3)
unnamed: FL201.1, J201.1 (V_{BUS}), U201.5 (VBUS)
unnamed: J201.4 (ID), TP201.1
unnamed: J201.6 (Shield), R201.1, R204.1

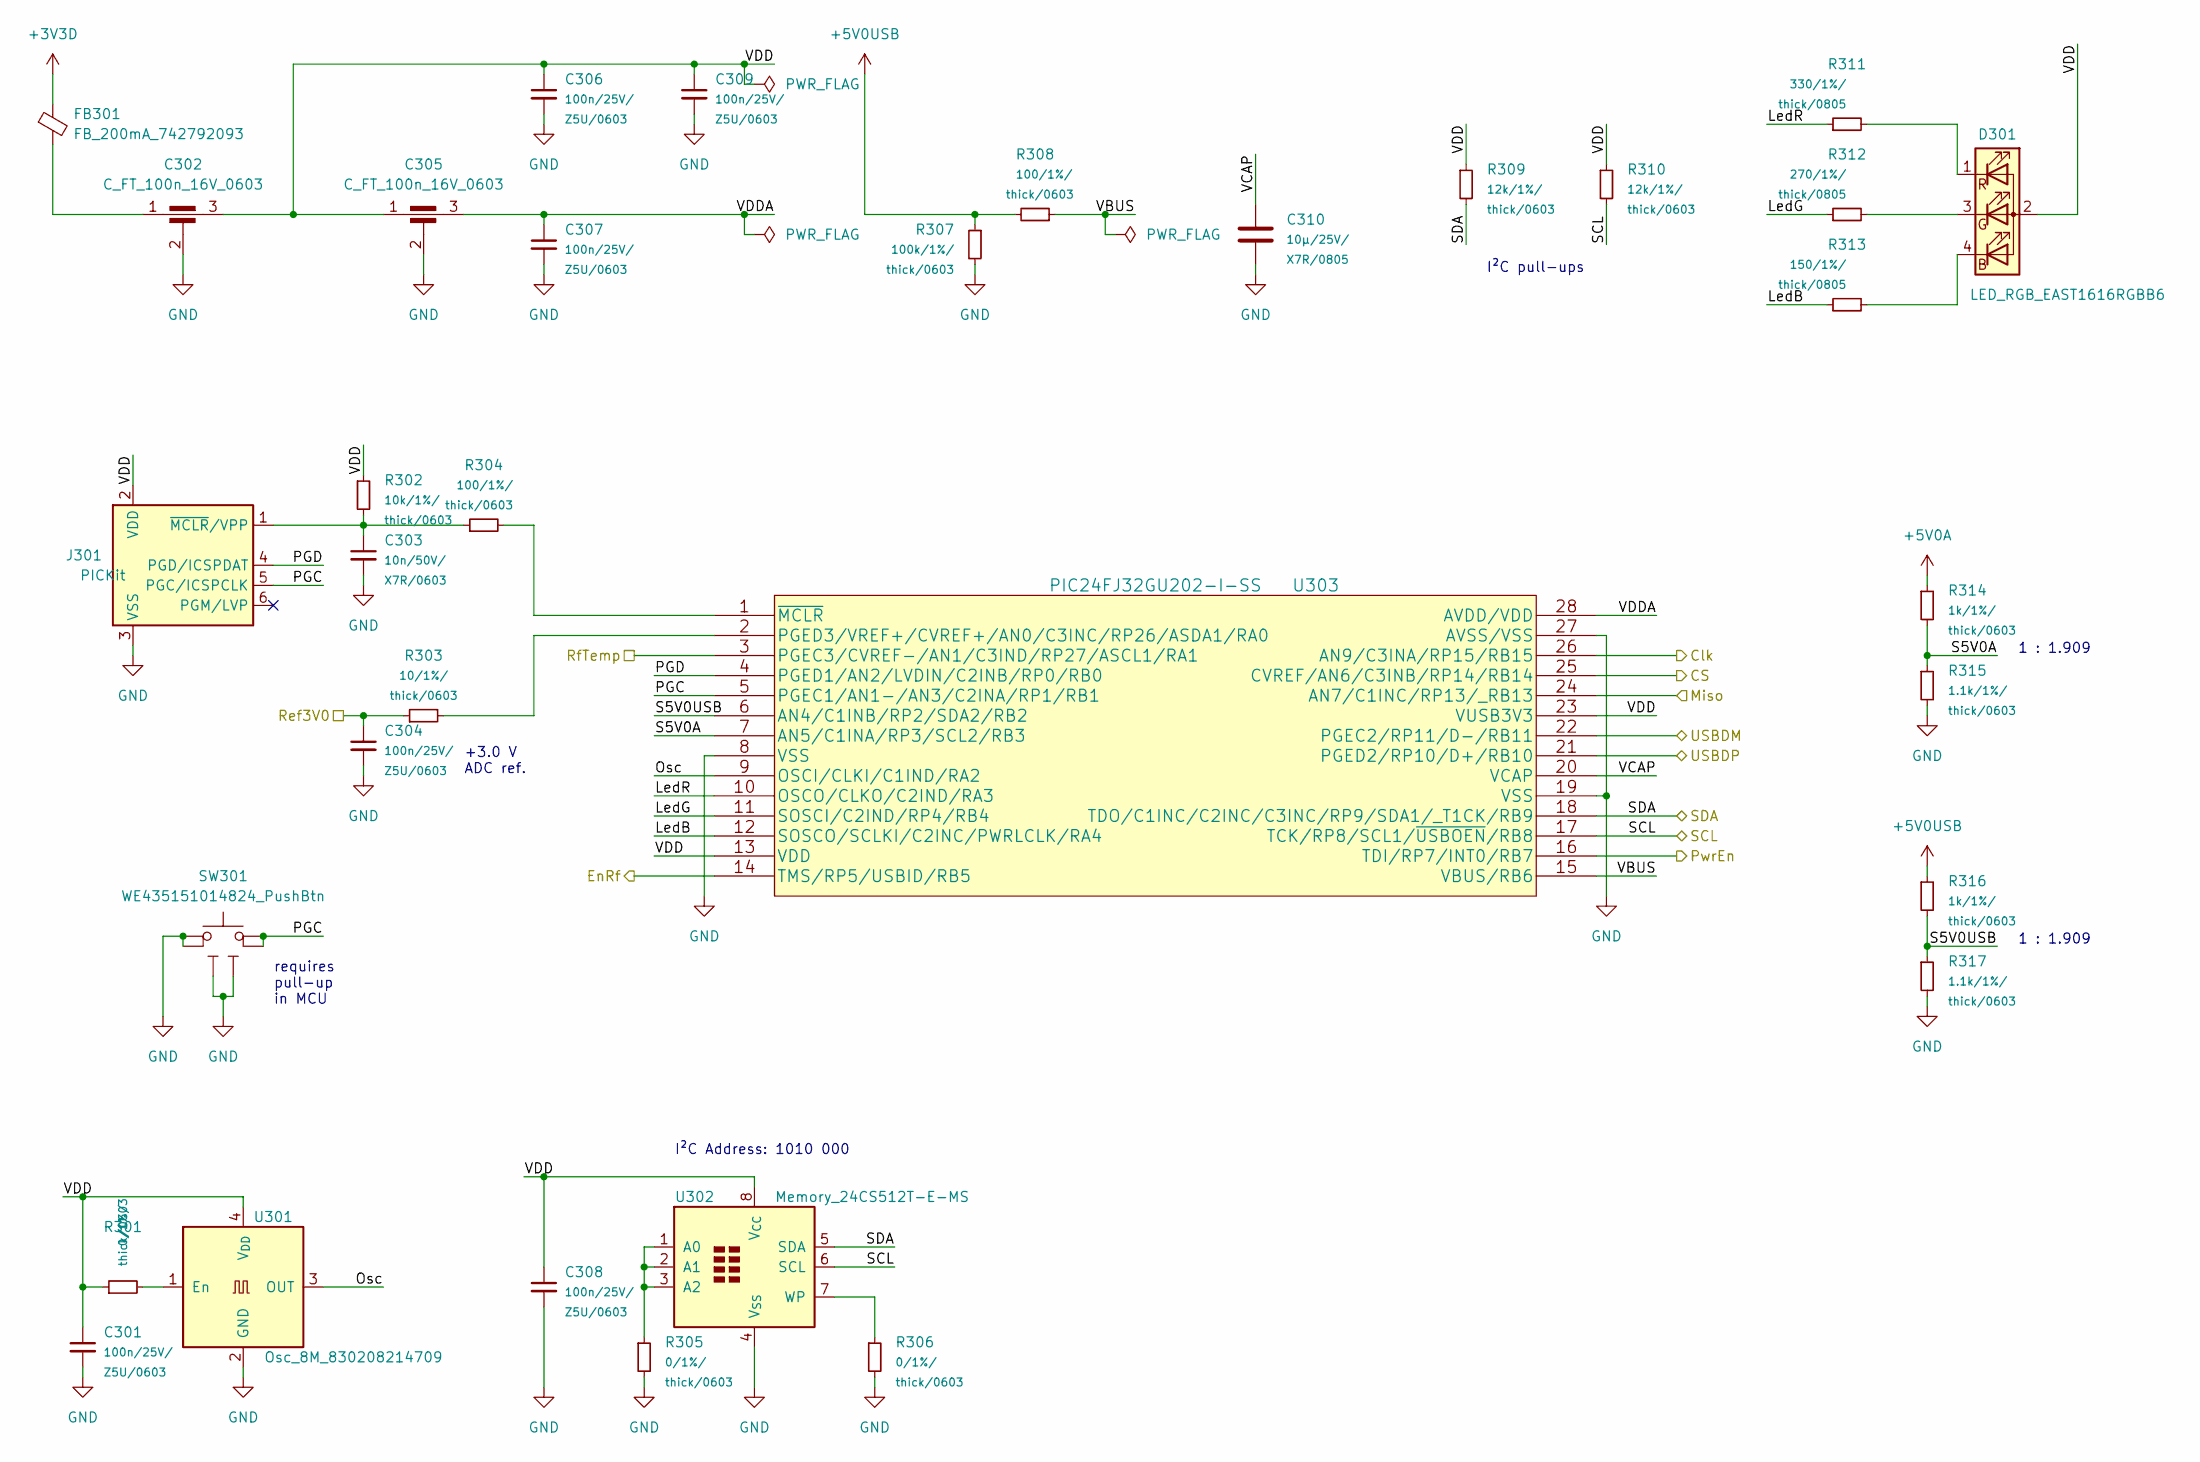
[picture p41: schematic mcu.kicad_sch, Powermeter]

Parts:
C301, C304, C306, C307, C308, C309: C_100n_25V_Z5U_0603_small; C_0603_1608Metric
C302, C305: C_FT_100n_16V_0603; C_Feedthru_0603
C303: C_10n_50V_X7R_0603_small; C_0603_1608Metric
C310: C_10µ_25V_X7R_0805; C_0805_2012Metric
D301: LED_RGB_EAST1616RGBB6; EAST1616RGBB6
FB301: FB_200mA_742792093; C_0805_2012Metric
J301: Conn_PICkit_1.27mm
R301, R305, R306: R_0_1P_thick_0603_small; R_0603_1608Metric
R302: R_10k_1P_thick_0603_small; R_0603_1608Metric
R303: R_10_1P_thick_0603_small; R_0603_1608Metric
R304, R308: R_100_1P_thick_0603_small; R_0603_1608Metric
R307: R_100k_1P_thick_0603_small; R_0603_1608Metric
R309, R310: R_12k_1P_thick_0603_small; R_0603_1608Metric
R311: R_330_1P_thick_0805_small; R_0805_2012Metric
R312: R_270_1P_thick_0805_small; R_0805_2012Metric
R313: R_150_1P_thick_0805_small; R_0805_2012Metric
R314, R316: R_1k_1P_thick_0603_small; R_0603_1608Metric
R315, R317: R_1k1_1P_thick_0603_small; R_0603_1608Metric
SW301: WE435151014824_PushBtn; WE435151014824
U301: Osc_8M_830208214709; Osc_IQD_2.0x1.6mm
U302: Memory_24CS512T-E-MS; SSOP-8_2.95x2.8mm_P0.65mm
U303: PIC24FJ32GU202-I-SS

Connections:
+3V3D: FB301.1; also elsewhere on the board
+5V0A: R314.1; also elsewhere on the board
+5V0USB: R307.1, R308.2, R316.1; also elsewhere on the board
/Converter/CS: U303.25 (CVREF/AN6/C3INB/RP14/RB14); also elsewhere on the board
/Converter/Clk: U303.26 (AN9/C3INA/RP15/RB15); also elsewhere on the board
/Converter/Miso: U303.24 (AN7/C1INC/RP13/_RB13); also elsewhere on the board
/Converter/Ref3V0: C304.1, R303.1; also elsewhere on the board
/MCU/EnRf: U303.14 (TMS/RP5/USBID/RB5); also elsewhere on the board
/MCU/LedB: R313.1, U303.12 (SOSCO/SCLKI/C2INC/PWRLCLK/RA4)
/MCU/LedG: R312.1, U303.11 (SOSCI/C2IND/RP4/RB4)
/MCU/LedR: R311.1, U303.10 (OSCO/CLKO/C2IND/RA3)
/MCU/Osc: U301.3 (OUT), U303.9 (OSCI/CLKI/C1IND/RA2)
/MCU/PGC: J301.5 (PGC/ICSPCLK), SW301.2 (B), SW301.4 (B), U303.5 (PGEC1/AN1-/AN3/C2INA/RP1/RB1)
/MCU/PGD: J301.4 (PGD/ICSPDAT), U303.4 (PGED1/AN2/LVDIN/C2INB/RP0/RB0)
/MCU/S5V0A: R314.2, R315.1, U303.7 (AN5/C1INA/RP3/SCL2/RB3)
/MCU/S5V0USB: R316.2, R317.1, U303.6 (AN4/C1INB/RP2/SDA2/RB2)
/MCU/SCL: R310.2, U302.6 (SCL), U303.17 (TCK/RP8/SCL1/~USBOEN/RB8); also elsewhere on the board
/MCU/SDA: R309.2, U302.5 (SDA), U303.18 (TDO/C1INC/C2INC/C3INC/RP9/SDA1/_T1CK/RB9); also elsewhere on the board
/MCU/USBDM: U303.22 (PGEC2/RP11/D-/RB11); also elsewhere on the board
/MCU/USBDP: U303.21 (PGED2/RP10/D+/RB10); also elsewhere on the board
/MCU/VBUS: R308.1, U303.15 (VBUS/RB6)
/MCU/VCAP: C310.1, U303.20 (VCAP)
/MCU/VDD: C301.1, C302.3, C305.1, C306.1, C308.1, C309.1, D301.2 (A), J301.2 (VDD), R301.1, R302.1, R309.1, R310.1, U301.4 (V_{DD}), U302.8 (V_{CC}), U303.13 (VDD), U303.23 (VUSB3V3)
/MCU/VDDA: C305.3, C307.1, U303.28 (AVDD/VDD)
/RF/TempSens: U303.3 (PGEC3/CVREF-/AN1/C3IND/RP27/ASCL1/RA1); also elsewhere on the board
/Supply/En: U303.16 (TDI/RP7/INT0/RB7); also elsewhere on the board
unnamed: C302.1, FB301.2
unnamed: C303.1, J301.1 (~MCLR/VPP), R302.2, R304.1
unnamed: D301.1 (RK), R311.2
unnamed: D301.3 (GK), R312.2
unnamed: D301.4 (BK), R313.2
unnamed: R301.2, U301.1 (En)
unnamed: R303.2, U303.2 (PGED3/VREF+/CVREF+/AN0/C3INC/RP26/ASDA1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)
unnamed: R304.2, U303.1 (~MCLR)
unnamed: R305.1, U302.1 (A0), U302.2 (A1), U302.3 (A2)
unnamed: R306.1, U302.7 (WP)

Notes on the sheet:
1 : 1.909
+3.0 V ADC ref.
requires pull-up in MCU
I²C Address: 1010 000
I²C pull-ups

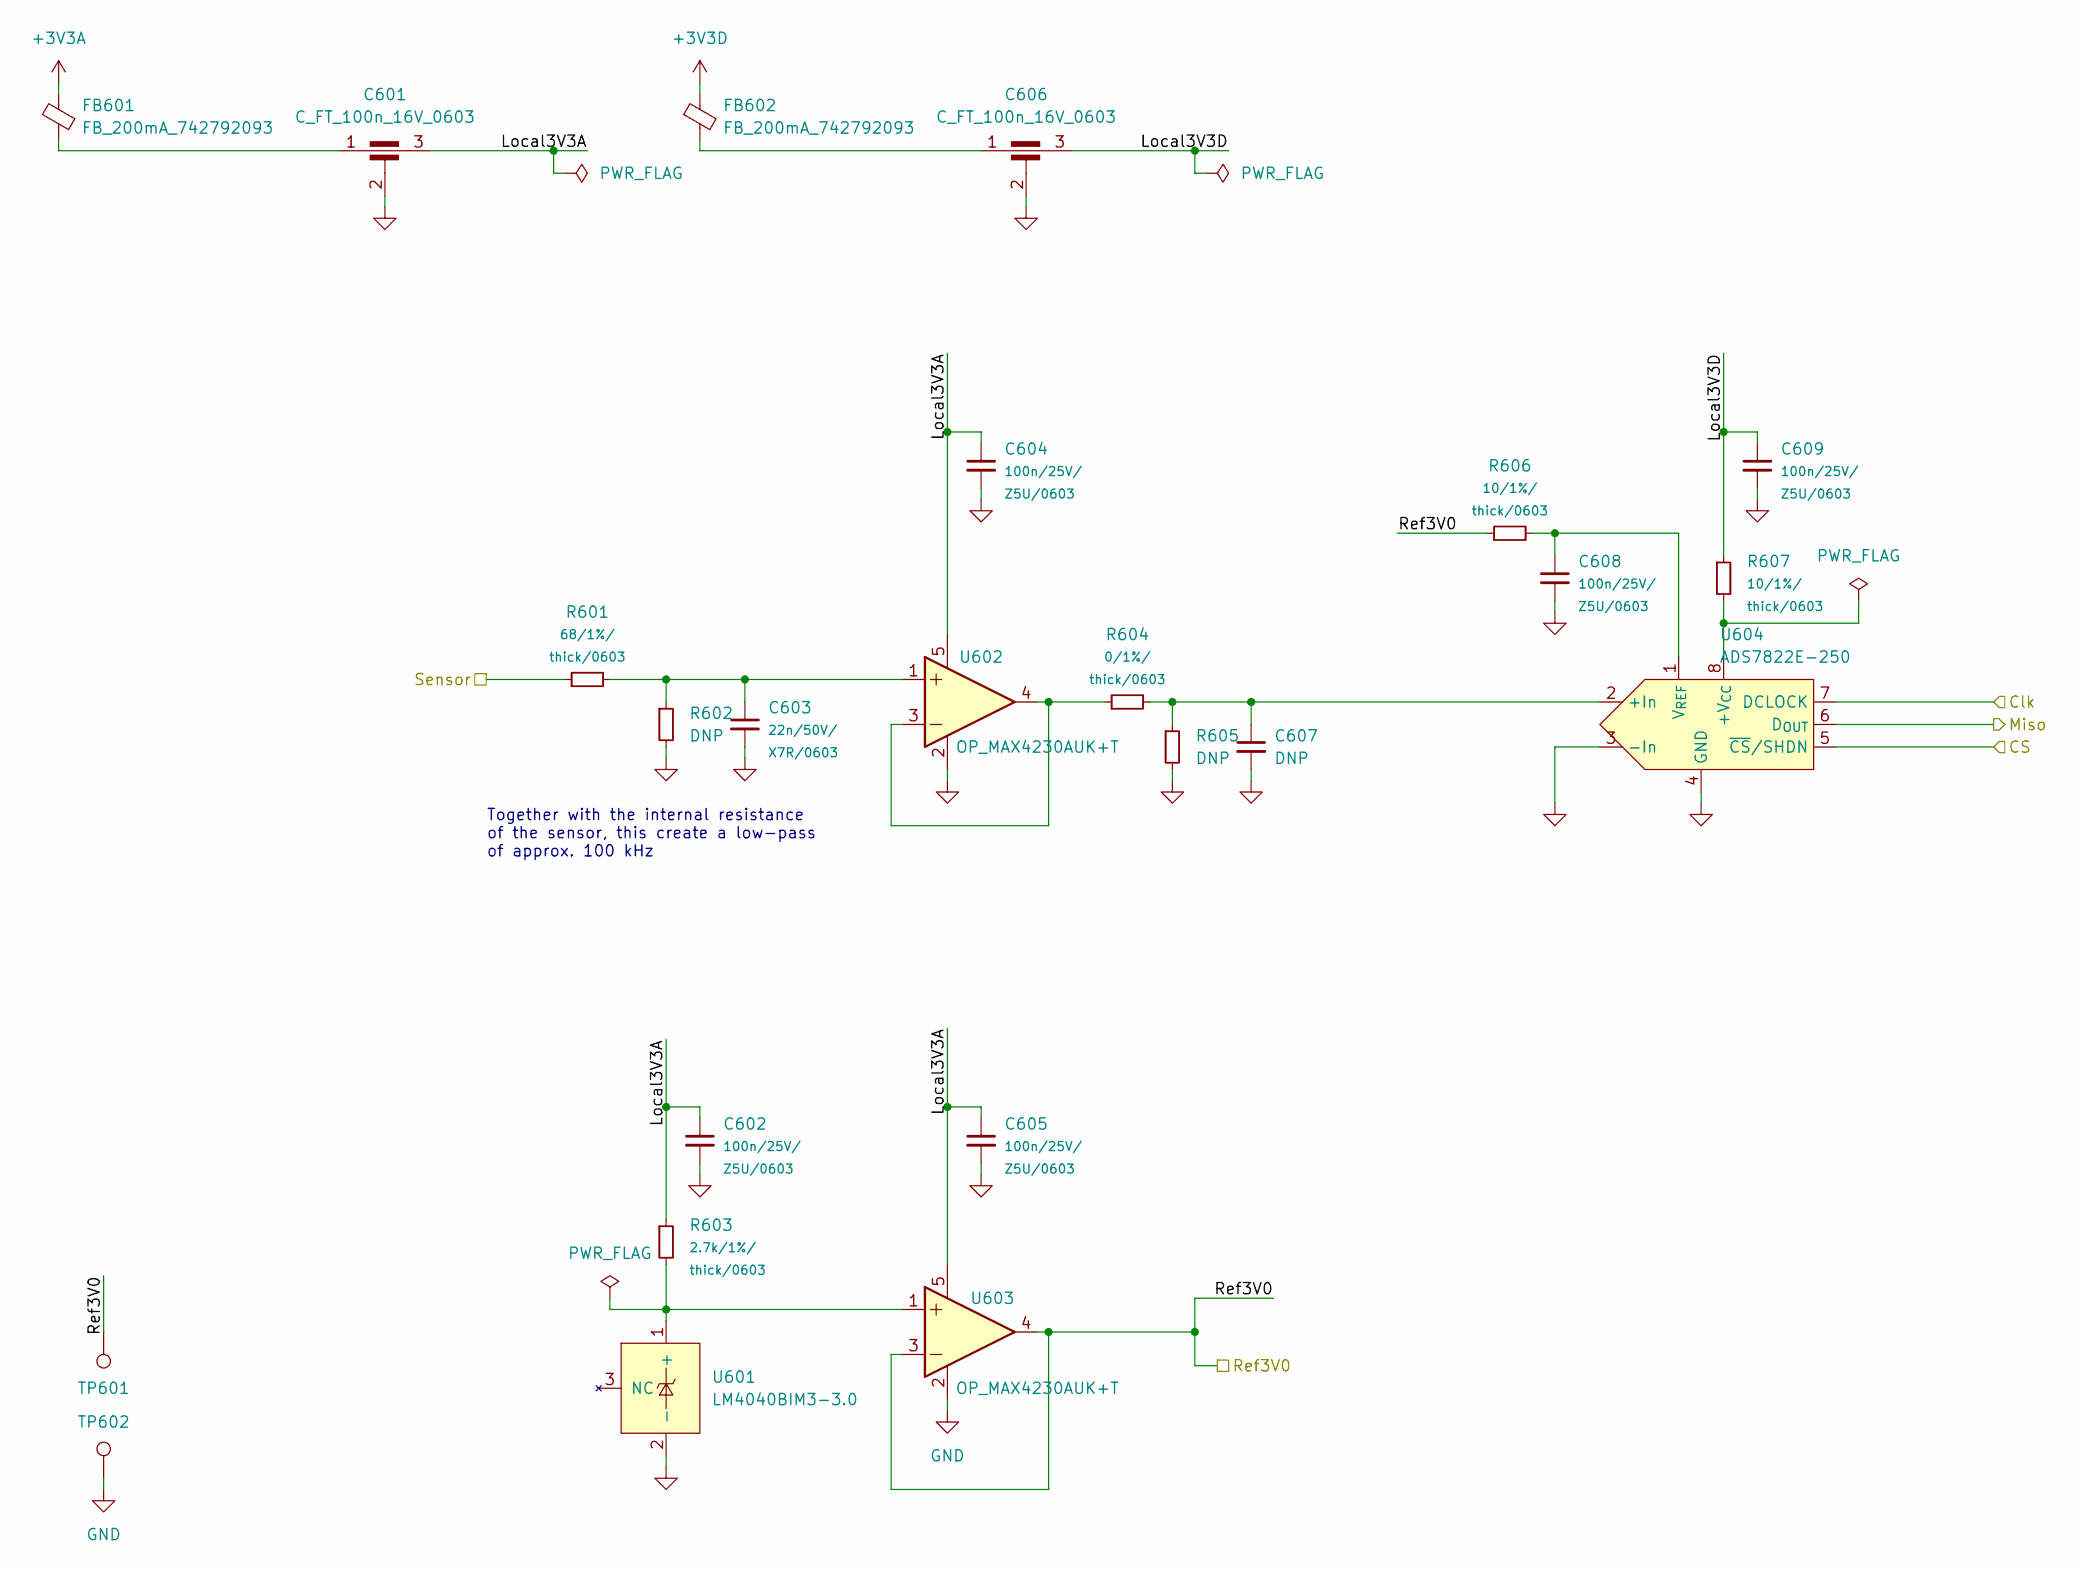
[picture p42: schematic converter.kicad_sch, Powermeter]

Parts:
C601, C606: C_FT_100n_16V_0603; C_Feedthru_0603
C602, C604, C605, C608, C609: C_100n_25V_Z5U_0603_small; C_0603_1608Metric
C603: C_22n_50V_X7R_0603_small; C_0603_1608Metric
C607: DNP; C_0603_1608Metric
FB601, FB602: FB_200mA_742792093; C_0805_2012Metric
R601: R_68_1P_thick_0603_small; R_0603_1608Metric
R602, R605: DNP; R_0603_1608Metric
R603: R_2k7_1P_thick_0603_small; R_0603_1608Metric
R604: R_0_1P_thick_0603_small; R_0603_1608Metric
R606, R607: R_10_1P_thick_0603_small; R_0603_1608Metric
TP601, TP602: TestPoint; TestPoint_Pad_D1.0mm
U601: LM4040BIM3-3.0; SOT-23
U602, U603: OP_MAX4230AUK+T; SOT-23-5
U604: ADS7822E-250; VSSOP-8_3.0x3.0mm_P0.65mm

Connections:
+3V3A: FB601.1; also elsewhere on the board
+3V3D: FB602.1; also elsewhere on the board
/Converter/CS: U604.5 (~CS/SHDN); also elsewhere on the board
/Converter/Clk: U604.7 (DCLOCK); also elsewhere on the board
/Converter/Local3V3A: C601.3, C602.1, C604.1, C605.1, R603.1, U602.5 (VDD), U603.5 (VDD)
/Converter/Local3V3D: C606.3, C609.1, R607.1
/Converter/Miso: U604.6 (D_{OUT}); also elsewhere on the board
/Converter/Ref3V0: R606.1, TP601.1, U603.3 (IN-), U603.4 (OUT); also elsewhere on the board
/RF/RfSens: R601.1; also elsewhere on the board
unnamed: C601.1, FB601.2
unnamed: C603.1, R601.2, R602.1, U602.1 (IN+)
unnamed: C606.1, FB602.2
unnamed: C607.1, R604.2, R605.1, U604.2 (+In)
unnamed: C608.1, R606.2, U604.1 (V_{REF})
unnamed: R603.2, U601.1 (+), U603.1 (IN+)
unnamed: R604.1, U602.3 (IN-), U602.4 (OUT)
unnamed: R607.2, U604.8 (+V_{CC})

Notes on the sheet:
Together with the internal resistance of the sensor, this create a low-pass of approx. 100 kHz

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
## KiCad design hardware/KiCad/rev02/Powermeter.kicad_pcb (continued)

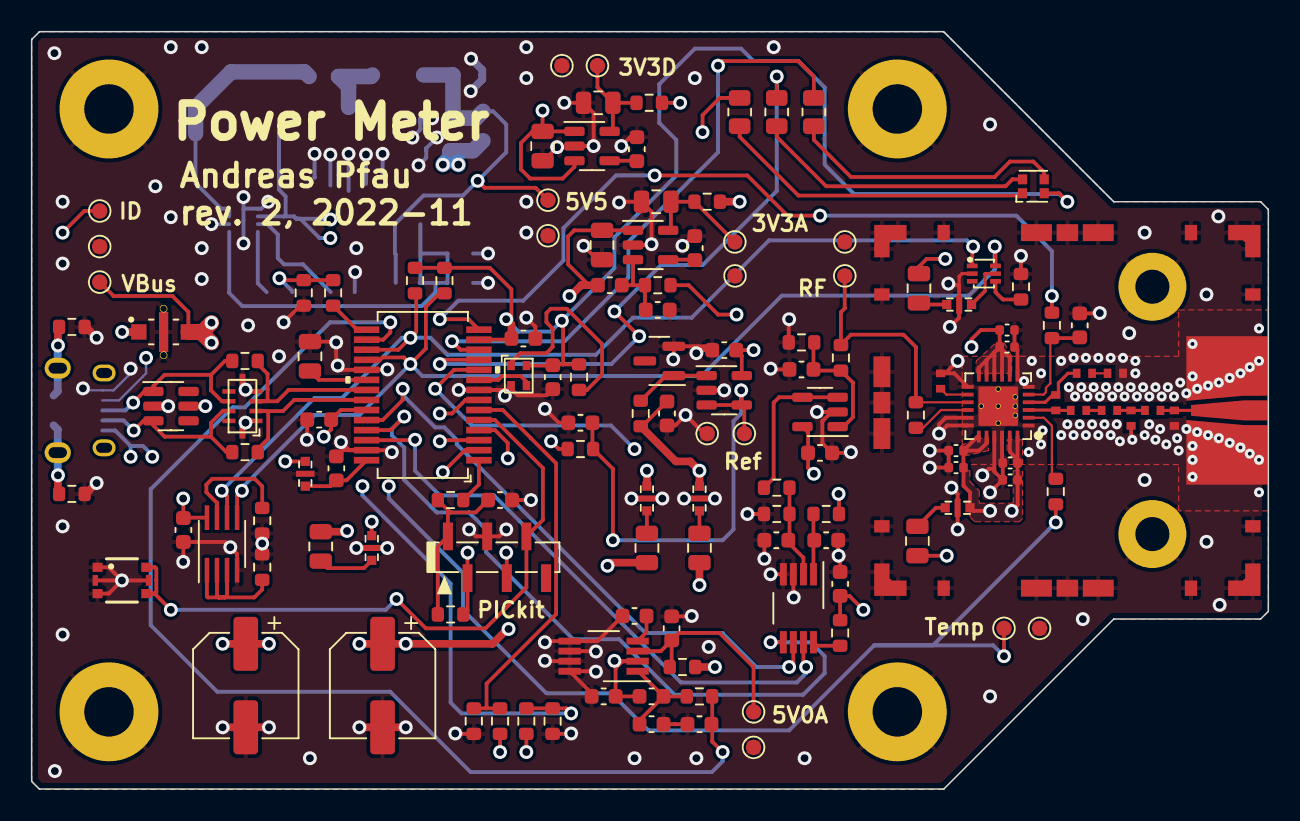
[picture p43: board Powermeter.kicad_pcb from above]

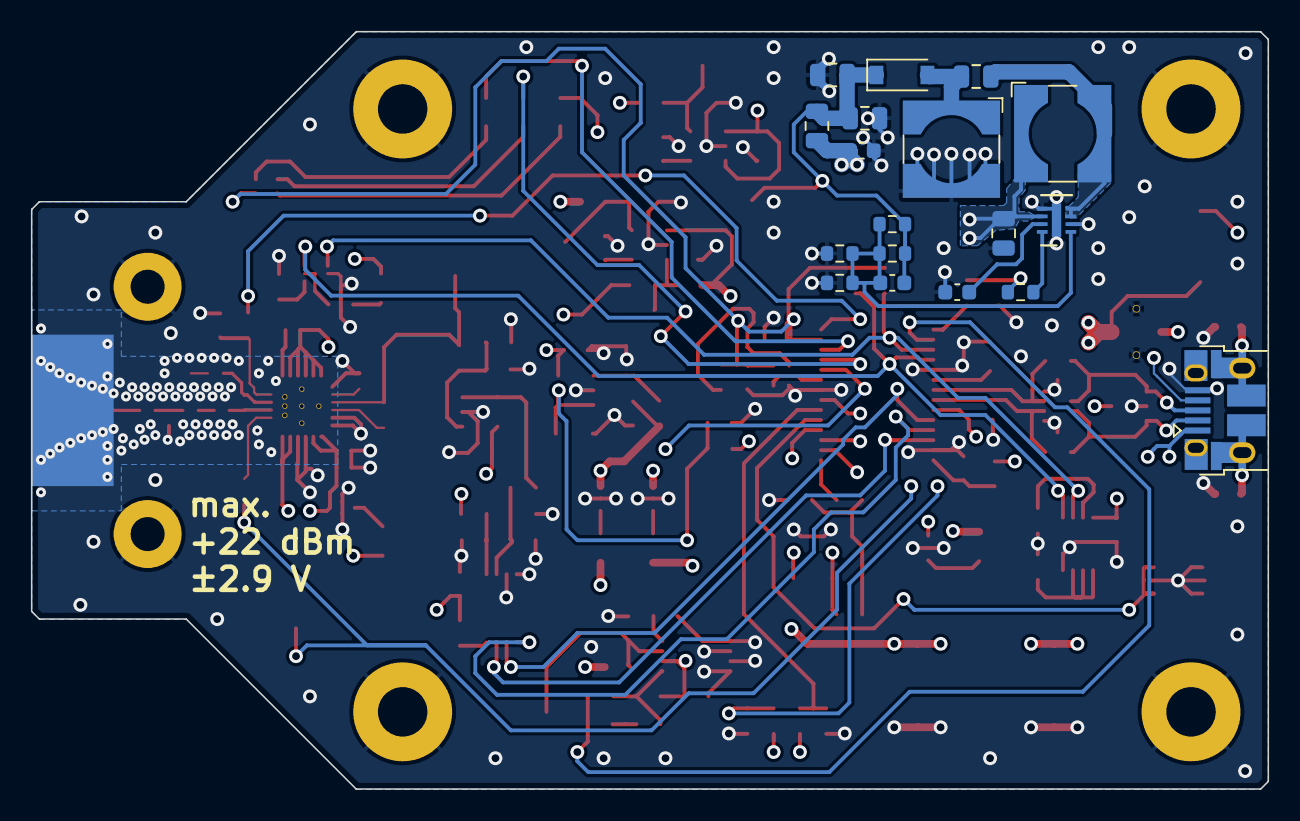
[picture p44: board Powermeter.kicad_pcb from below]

Board: 4 copper layers, 80.0 x 49.0 mm, 162 parts (18 on the bottom side), 84 nets.

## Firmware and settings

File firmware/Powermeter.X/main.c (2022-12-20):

#include "mcc_generated_files/system.h"
#include "mcc_generated_files/interrupt_manager.h"

#include "infrastructure.h"
#include "tempsens.h"
#include "rfsens.h"
#include "memory.h"
#include "ui.h"
#include "usb.h"
#include "cal.h"
#include "render.h"

#include <stdbool.h>


int main(void)
{
    SYSTEM_Initialize();
    INTERRUPT_GlobalEnable();
    
    infra_init();
    temp_init();
    rf_init();
    mem_init();
    cal_init();
    render_init();
    
    infra_enable_supply(1);
    infra_enable_rf(1);
    
    usb_init();
    ui_init();
    
    while (1)
    {
        rf_loop();
        ui_loop();
        usb_loop();
    }

    return 1;
}

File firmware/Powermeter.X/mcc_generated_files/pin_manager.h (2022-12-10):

/**
  PIN MANAGER Generated Driver File

  @Company:
    Microchip Technology Inc.

  @File Name:
    pin_manager.h

  @Summary:
    This is the generated manager file for the PIC24 / dsPIC33 / PIC32MM MCUs device.  This manager
    configures the pins direction, initial state, analog setting.
    The peripheral pin select, PPS, configuration is also handled by this manager.

  @Description:
    This source file provides implementations for PIN MANAGER.
    Generation Information :
        Product Revision  :  PIC24 / dsPIC33 / PIC32MM MCUs - 1.171.1
        Device            :  PIC24FJ32GU202
    The generated drivers are tested against the following:
        Compiler          :  XC16 v1.70
        MPLAB 	          :  MPLAB X v5.50
*/

/*
    (c) 2020 Microchip Technology Inc. and its subsidiaries. You may use this
    software and any derivatives exclusively with Microchip products.

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
    IN NO EVENT WILL MICROCHIP BE LIABLE FOR ANY INDIRECT, SPECIAL, PUNITIVE,
    INCIDENTAL OR CONSEQUENTIAL LOSS, DAMAGE, COST OR EXPENSE OF ANY KIND
    WHATSOEVER RELATED TO THE SOFTWARE, HOWEVER CAUSED, EVEN IF MICROCHIP HAS
    BEEN ADVISED OF THE POSSIBILITY OR THE DAMAGES ARE FORESEEABLE. TO THE
    FULLEST EXTENT ALLOWED BY LAW, MICROCHIP'S TOTAL LIABILITY ON ALL CLAIMS IN
    ANY WAY RELATED TO THIS SOFTWARE WILL NOT EXCEED THE AMOUNT OF FEES, IF ANY,
    THAT YOU HAVE PAID DIRECTLY TO MICROCHIP FOR THIS SOFTWARE.

    MICROCHIP PROVIDES THIS SOFTWARE CONDITIONALLY UPON YOUR ACCEPTANCE OF THESE
    TERMS.
*/

#ifndef _PIN_MANAGER_H
#define _PIN_MANAGER_H
/**
    Section: Includes
*/
#include <xc.h>

/**
    Section: Device Pin Macros
*/
/**
  @Summary
    Sets the GPIO pin, RA1, high using LATA1.

  @Description
    Sets the GPIO pin, RA1, high using LATA1.

  @Preconditions
    The RA1 must be set to an output.

  @Returns
    None.

  @Param
    None.

  @Example
    <code>
    // Set RA1 high (1)
    Channel_RfTemp_SetHigh();
    </code>

*/
#define Channel_RfTemp_SetHigh()          (_LATA1 = 1)
/**
  @Summary
    Sets the GPIO pin, RA1, low using LATA1.

  @Description
    Sets the GPIO pin, RA1, low using LATA1.

  @Preconditions
    The RA1 must be set to an output.

  @Returns
    None.

  @Param
    None.

  @Example
    <code>
    // Set RA1 low (0)
    Channel_RfTemp_SetLow();
    </code>

*/
#define Channel_RfTemp_SetLow()           (_LATA1 = 0)
/**
  @Summary
    Toggles the GPIO pin, RA1, using LATA1.

  @Description
    Toggles the GPIO pin, RA1, using LATA1.

  @Preconditions
    The RA1 must be set to an output.

  @Returns
    None.

  @Param
    None.

  @Example
    <code>
    // Toggle RA1
    Channel_RfTemp_Toggle();
    </code>

*/
#define Channel_RfTemp_Toggle()           (_LATA1 ^= 1)
/**
  @Summary
    Reads the value of the GPIO pin, RA1.

  @Description
    Reads the value of the GPIO pin, RA1.

  @Preconditions
    None.

  @Returns
    None.

  @Param
    None.

  @Example
    <code>
    uint16_t portValue;

    // Read RA1
    postValue = Channel_RfTemp_GetValue();
    </code>

*/
#define Channel_RfTemp_GetValue()         _RA1
/**
  @Summary
    Configures the GPIO pin, RA1, as an input.

  @Description
    Configures the GPIO pin, RA1, as an input.

  @Preconditions
    None.

  @Returns
    None.

  @Param
    None.

  @Example
    <code>
    // Sets the RA1 as an input
    Channel_RfTemp_SetDigitalInput();
    </code>

*/
#define Channel_RfTemp_SetDigitalInput()  (_TRISA1 = 1)
/**
  @Summary
    Configures the GPIO pin, RA1, as an output.

  @Description
    Configures the GPIO pin, RA1, as an output.

  @Preconditions
    None.

  @Returns
    None.

  @Param
    None.

  @Example
    <code>
    // Sets the RA1 as an output
    Channel_RfTemp_SetDigitalOutput();
    </code>

*/
#define Channel_RfTemp_SetDigitalOutput() (_TRISA1 = 0)
/**
  @Summary
    Sets the GPIO pin, RA3, high using LATA3.

  @Description
    Sets the GPIO pin, RA3, high using LATA3.

  @Preconditions
    The RA3 must be set to an output.

  @Returns
    None.

  @Param
    None.

  @Example
    <code>
    // Set RA3 high (1)
    IO_LedR_SetHigh();
    </code>

*/
#define IO_LedR_SetHigh()          (_LATA3 = 1)
/**
  @Summary
    Sets the GPIO pin, RA3, low using LATA3.

  @Description
    Sets the GPIO pin, RA3, low using LATA3.

  @Preconditions
    The RA3 must be set to an output.

  @Returns
    None.

  @Param
    None.

  @Example
    <code>
    // Set RA3 low (0)
    IO_LedR_SetLow();
    </code>

*/
#define IO_LedR_SetLow()           (_LATA3 = 0)
/**
  @Summary
    Toggles the GPIO pin, RA3, using LATA3.

  @Description
    Toggles the GPIO pin, RA3, using LATA3.

  @Preconditions
    The RA3 must be set to an output.

  @Returns
    None.

  @Param
    None.

  @Example
    <code>
    // Toggle RA3
    IO_LedR_Toggle();
    </code>

*/
#define IO_LedR_Toggle()           (_LATA3 ^= 1)
/**
  @Summary
    Reads the value of the GPIO pin, RA3.

  @Description
    Reads the value of the GPIO pin, RA3.

  @Preconditions
    None.

  @Returns
    None.

  @Param
    None.

  @Example
    <code>
    uint16_t portValue;

    // Read RA3
    postValue = IO_LedR_GetValue();
    </code>

*/
#define IO_LedR_GetValue()         _RA3
/**
  @Summary
    Configures the GPIO pin, RA3, as an input.

  @Description
    Configures the GPIO pin, RA3, as an input.

  @Preconditions
    None.

  @Returns
    None.

  @Param
    None.

  @Example
    <code>
    // Sets the RA3 as an input
    IO_LedR_SetDigitalInput();
    </code>

*/
#define IO_LedR_SetDigitalInput()  (_TRISA3 = 1)
/**
  @Summary
    Configures the GPIO pin, RA3, as an output.

  @Description
    Configures the GPIO pin, RA3, as an output.

  @Preconditions
    None.

  @Returns
    None.

  @Param
    None.

  @Example
    <code>
    // Sets the RA3 as an output
    IO_LedR_SetDigitalOutput();
    </code>

*/
#define IO_LedR_SetDigitalOutput() (_TRISA3 = 0)
/**
  @Summary
    Sets the GPIO pin, RA4, high using LATA4.

  @Description
    Sets the GPIO pin, RA4, high using LATA4.

  @Preconditions
    The RA4 must be set to an output.

  @Returns
    None.

  @Param
    None.

  @Example
    <code>
    // Set RA4 high (1)
    IO_LedB_SetHigh();
    </code>

*/
#define IO_LedB_SetHigh()          (_LATA4 = 1)
/**
  @Summary
    Sets the GPIO pin, RA4, low using LATA4.

  @Description
    Sets the GPIO pin, RA4, low using LATA4.

  @Preconditions
    The RA4 must be set to an output.

  @Returns
    None.

  @Param
    None.

  @Example
    <code>
    // Set RA4 low (0)
    IO_LedB_SetLow();
    </code>

*/
#define IO_LedB_SetLow()           (_LATA4 = 0)
/**
  @Summary
    Toggles the GPIO pin, RA4, using LATA4.

  @Description
    Toggles the GPIO pin, RA4, using LATA4.

  @Preconditions
    The RA4 must be set to an output.

  @Returns
    None.

  @Param
    None.

  @Example
    <code>
    // Toggle RA4
    IO_LedB_Toggle();
    </code>
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

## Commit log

2022-12-10 Some cleanup
    [Capacitor_Feedthru_0805.step, EZA-DLU.stp, Molex_SMA_732511150.stp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]
2022-12-18 Worked on cal data; not working yet
    [memory.c, memory.h, ui.c]
2022-12-23 Worked on cal; fixed an issue with endianness of data; fixed a rendering issue
    [ui.c]
2022-12-23 Fixed EEPROM write timing; updated doc
    [memory.c, memory.h]
2022-12-29 Some FW tweaks and fixes
    [rfsens.c, ui.c]

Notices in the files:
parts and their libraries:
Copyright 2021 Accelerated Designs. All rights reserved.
